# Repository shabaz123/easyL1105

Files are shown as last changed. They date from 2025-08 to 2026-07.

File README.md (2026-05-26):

# easyL1105 - What is it?
This repository contains resources for working with Texas Instruments MSPM0 microcontrollers, and in particular, the MSPM0L1105 microcontroller.
KiCad files, and Gerber files are present for building a simple development board, called easyL1105. 

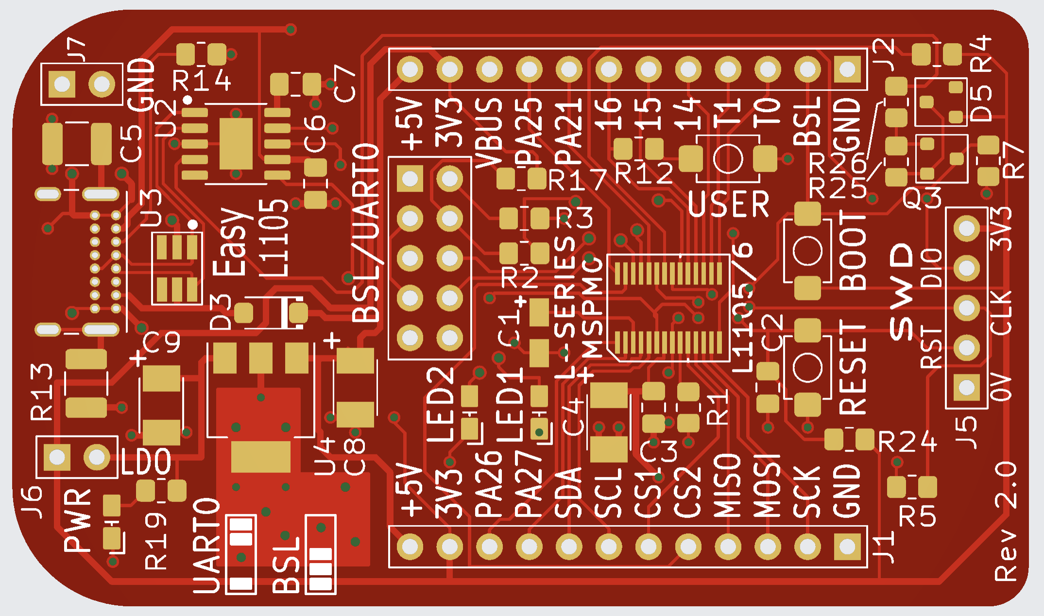
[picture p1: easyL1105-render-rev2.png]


The repository also contains Gerber files for a smaller miniL1105 board:

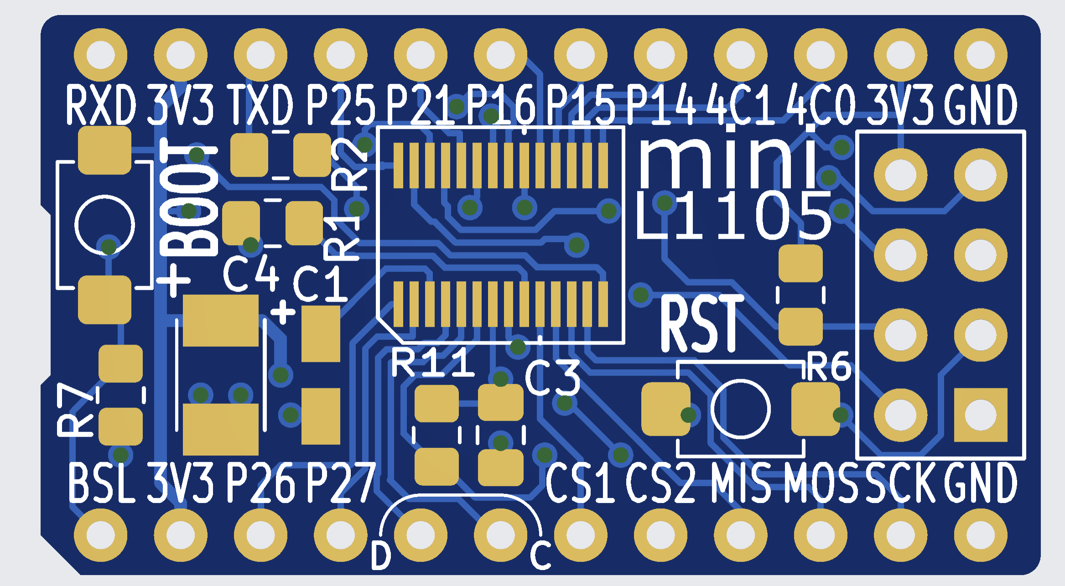
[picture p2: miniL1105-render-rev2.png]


There is also an example starter project, which can be built with Keil or GCC.

# Circuit Diagrams
## easyL1105
<a href="easyL1105_schematic_rev2.pdf">
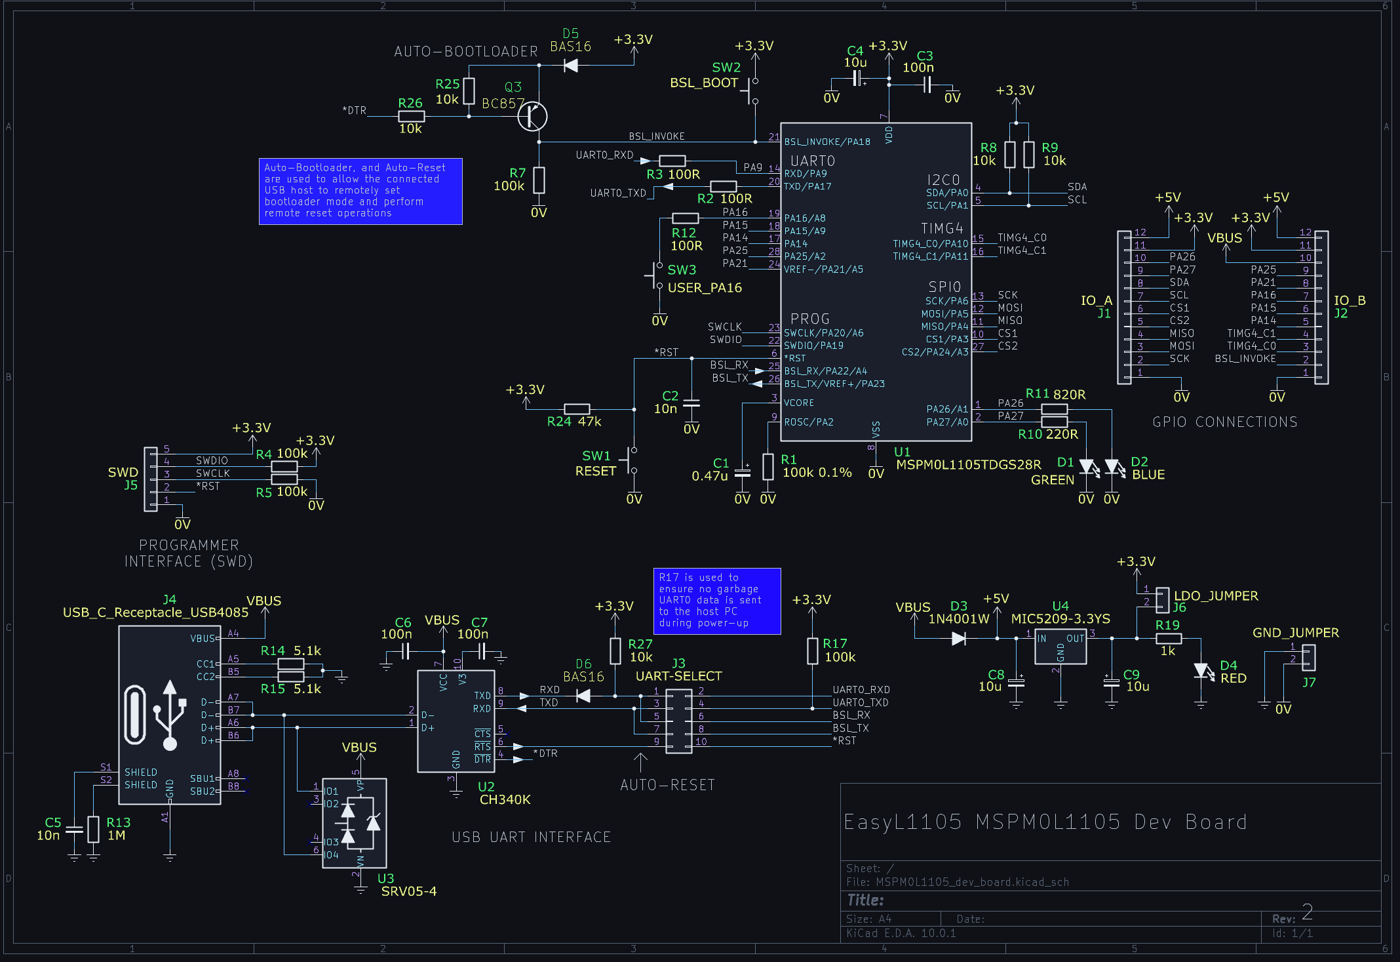
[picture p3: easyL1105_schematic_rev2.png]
  
</a>

## miniL1105
<a href="miniL1105-schematic-rev2.pdf">
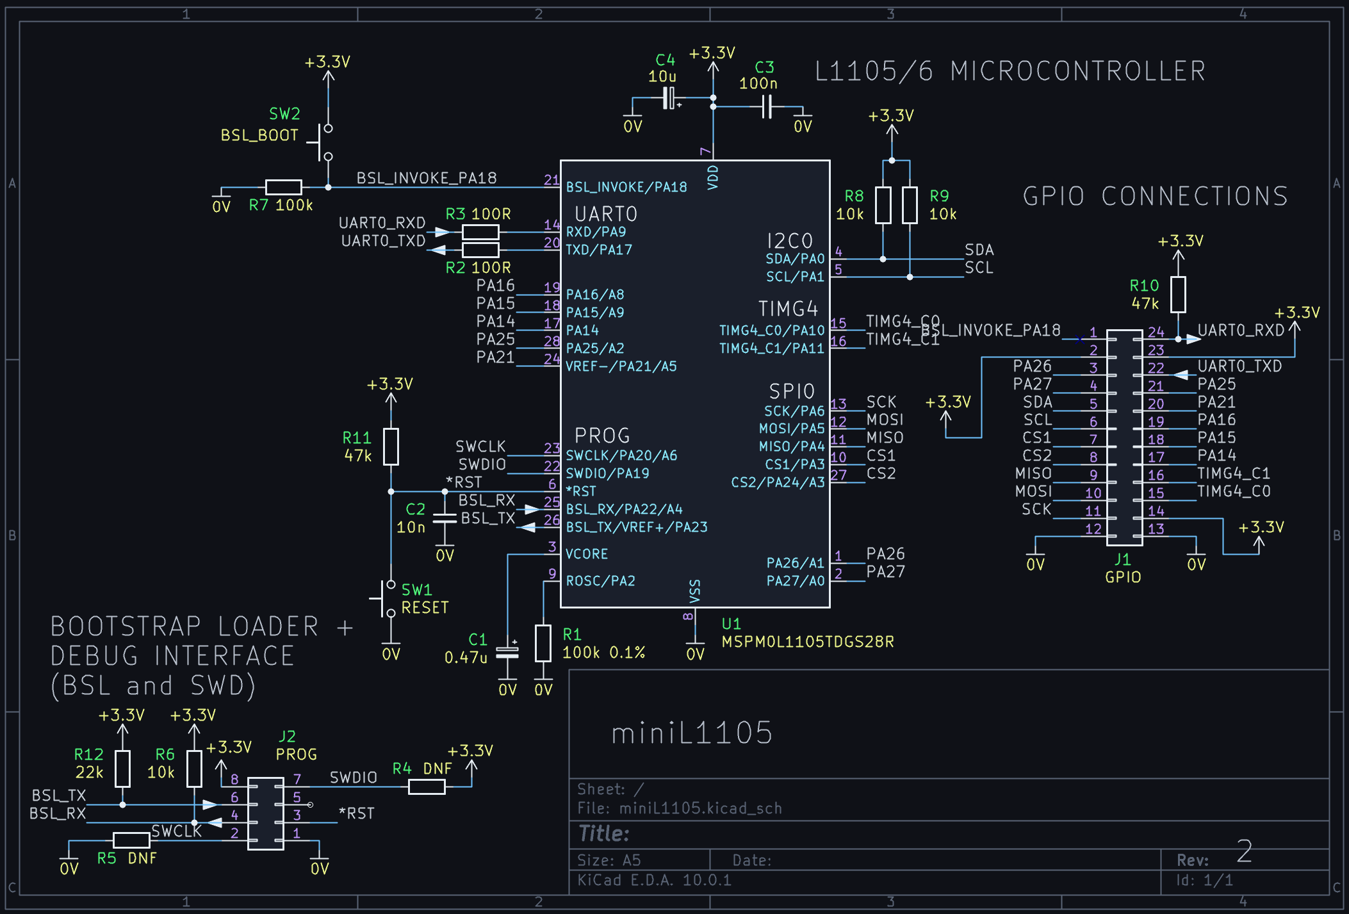
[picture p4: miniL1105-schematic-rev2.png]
  
</a>

## Note for old Rev 1 Boards
The Rev 1 boards had a known bug; they were missing a 47k pull-up resistor from the *RST pin (pin 6 on the microcontroller) to +3.3V. The newer Rev 2 boards do not have this issue.

If you have a Rev 1 board, the fix is easy, it is possible to patch a resistor onto the underside of the PCB, using an 0805 sized resistor and a short length of 30 AWG Kynar wire.

The easyL1105 Rev 1 board allocates pins PA17(TXD) and PA18(RXD) for UART0, but since PA18(RXD) also has a BOOT function for enabling bootloader mode, there is the unfortunate situation that if the "BSL/UART0" board jumpers are configured to direct UART0 to the USB-UART chip, the pin is in BOOT mode during reset. One workaround for now is to not fit the rightmost jumper (rightmost when the "EasyL1105" and "BSL/UART0" text is the correct way up) during board reboot or power-up, and then fit it later. The better fix is in Rev 2, where a different GPIO pin (PA9) is used in place of PA18(RXD), so that it doesn't clash with the BOOT function

# easyL1105 Parts List
NOTE: The parts lists in this repository are for the Rev 1 board. They need to be updated for Rev 2. However, it is easy to read off the schematic what parts are required. 

| REF | QTY | VALUE | DESCRIPTION |
| --- | --- | --- | --- |
| C1 | 1 | 0.47u | Tant Cap Case A example: T491A474M025AT |
| C2, C5 | 2 | 10n | 0805 MLCC Capacitor |
| C3,C6,C7 | 3 | 100n | 0805 MLCC Capacitor |
| C4,C8,C9 | 3 | 10u 16V | Tant Cap Case B example: TAJB106K016RNJ |
| D1 | 1 | GREEN | LED GREEN 0603 |
| D2 | 1 | BLUE | LED BLUE 0603 |
| D3 | 1 | 1N4001W | Diode SOD-123 |
| D4 | 1 | PWR | LED RED 0603 |
| J1, J2, J5, J6, J7 | 1 | Header SIL | Pin Header 2.54mm SIL 40-way (snapped to fit) |
| J3 | 1 | 2x5 DIL | Pin Header 2.54mm DIL 10-way (2x5 way) |
| J4 | 1 | USB4085 | Socket GCT USB4805 / XUNPU USB-B10-BRW |
| R1 | 1 | 100k 0.1% | 0805 Resistor 0.1% |
| R2,R3,R12 | 3 | 100R | 0805 Resistor |
| R4,R5,R7 | 3 | 100k | 0805 Resistor |
| R8,R9,R16 | 3 | 10k | 0805 Resistor |
| R10 | 1 | 220R | 0805 Resistor |
| R11 | 1 | 820R | 0805 Resistor |
| R19 | 1 | 1k | 0805 Resistor |
| R13 | 1 | 1M | 0805 Resistor |
| R14,R15 | 2 | 5.1k | 0805 Resistor |
| SW1, 2, 3 | 3 | Tact Switch | Tact Button 4x3mm GCT SWT0110 |
| U1 | 1 | MSPM0L1105TDGS28R | TI MSPM0 L1105 VSSOP28 DGS |
| U2 | 1 | CH340K | WCH USB UART IC SSOP-10-1EP |
| U3 | 1 | SRV05-4 | ESD Diode Array SOT23-6 |
| U4 | 1 | MIC5209-3.3YS | LDO 3.3V SOT-223 |
| RFIX1 | 1 | 47k | 0805 Resistor, patched between \*RST and 3.3V |
| n/a | 5 | Shorting Jumpers  | Jumpers 2-pin 2.54mm (Red, Black, Green x2, Blue) |

# Example Project
Go into the [**MyStarterProject**](https://github.com/shabaz123/easyL1105/tree/main/MyStarterProject) folder to see an example project called **app_L1105** (and if you plan to use GCC on Linux, then you need the **set_env.sh** file that is also in the MyStarterProject folder; save it to any convenient location). 

Go into the [**app_L1105**](https://github.com/shabaz123/easyL1105/tree/main/MyStarterProject/app_L1105) folder within MyStarterProject, and you'll find README notes explaining how to set up your PC and how to build the code.

If you were creating your own app based on the starter code, then rename the folder MyStarterProject to whatever name you want (for instance, MyLEDProject), and within there, retain the app_L1105 folder name (otherwise, you'd have to modify the contents of IDE files or makefiles). Then, edit the main.c file to do whatever you wish.

# Uploading your Application Firmware to the Microcontroller
Once you have built the example project, you'll want to upload it into the microcontroller. The easyL1105 board has a built-in USB-to-UART adapter. The miniL1105 board will require an external 3.3V logic level USB-UART adapter.

## Set Board Jumpers and Plug into PC
If you're using the easyL1105 board, ensure that two jumpers (green in the photo below) are fitted to direct the USB-UART to **BSL**, and not to UART0. Ensure that the PWR and GND jumpers are fitted (red and black in the photo below).

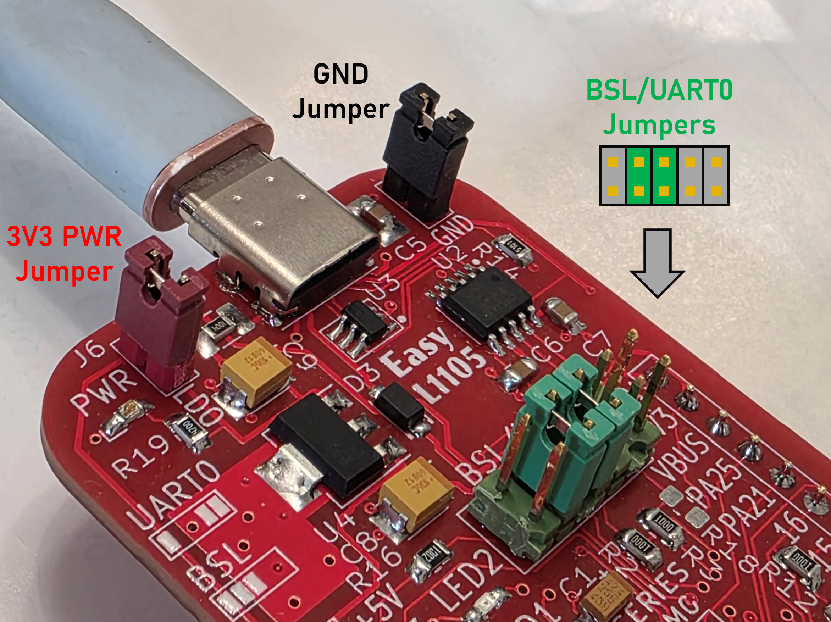
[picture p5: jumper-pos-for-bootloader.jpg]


Attach the board using the USB cable to your PC, and check what port number is associated with it (for example, it may be a number like COM7 if you're using a Windows PC). If you don't see any port, then there may be a fault with the USB-UART circuitry, or an issue with the USB cable perhaps.

## Install and Run UniFlash
Download and install TI UniFlash. Run it, and at the top-right, set **Setting:Manual**. Next, under **Device**, click on **Category:MSP** and then type **MSPM0L110x** and you'll see a selection titled **MSPM0L110X(BOOTLOADER) Serial**. Click to select that.

Next, click on **Start**. 

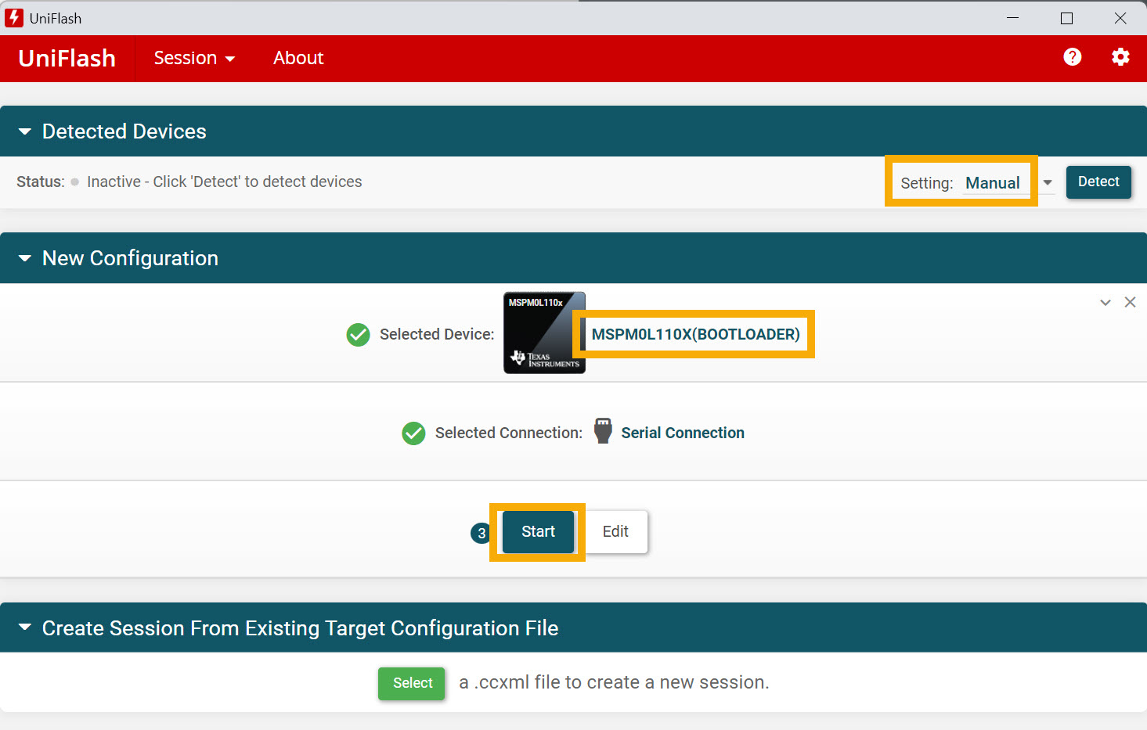
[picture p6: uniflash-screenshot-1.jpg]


You'll see a set of boxes appear. Click the empty text entry box to the right of **Application Image 1** and in the file browser that appears, browse to your built firmware file, which will have a **.hex** suffix, for instance, **app_L1105.hex**.

**Don't** press the Load Image button that appears just yet!

Instead, scroll further down, and you'll see a random COM port selected. In that box, type the correct COM port.

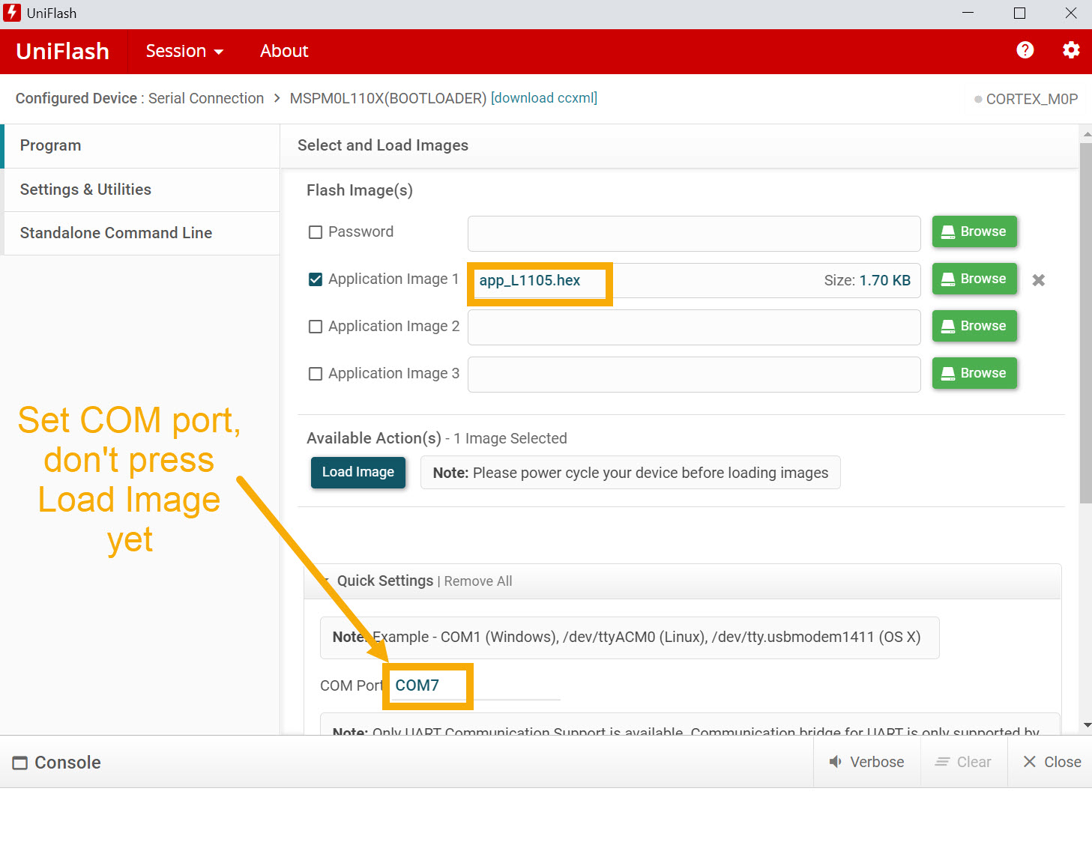
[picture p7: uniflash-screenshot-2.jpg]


## Set Board to Bootloader Mode
Hold down the **BOOT** button on the board, press and release the **RESET** button, then release the **BOOT** button.

## Upload the Firmware
Now you can go back to the **Load Image** button in UniFlash, and press it.

Initially it may take a few seconds (or longer), but eventually you should see output like the following:

```
[21/08/2025, 23:56:17] [INFO] CORTEX_M0P: MSPM0L110x(Bootloader)
[21/08/2025, 23:56:17] [INFO] CORTEX_M0P: Invoking Bootloader....
[21/08/2025, 23:56:18] [ERROR] CORTEX_M0P: Automatic Bootloader invocation failed with response....1
[21/08/2025, 23:56:18] [ERROR] CORTEX_M0P: Try manual Bootloader Invocation...
[21/08/2025, 23:56:19] [INFO] CORTEX_M0P:
[21/08/2025, 23:56:19] [INFO] CORTEX_M0P: BSL Connected
[21/08/2025, 23:56:19] [INFO] CORTEX_M0P: Command Interpreter version: [0x0100] Build ID: [0x0100] Application version: [0x00000000] Active Plugin Interface version: [0x0001] BSL Max buffer size: [0x06C0] BSL Buffer Start address: [0x20000160] BCR Config ID: [0x00000x0001] BSL Config ID [0x00000x0001]
[21/08/2025, 23:56:19] [INFO] CORTEX_M0P: [80] [01] [00] [19] [B2] [B8] [96] [49]
[21/08/2025, 23:56:19] [INFO] CORTEX_M0P: {00}{08} {19} {00} {31} {00} {01} {00} {01} {00} {00} {00} {00} {01} {00} {C0} {06} {60} {01} {00} {20} {01} {00} {00} {00} {01} {00} {00} {00} {49} {61} {57} {8C}
[21/08/2025, 23:56:19] [INFO] CORTEX_M0P: BSL Password is correct!
[21/08/2025, 23:56:19] [INFO] CORTEX_M0P: [80] [21] [00] [21] [FF] [FF] [FF] [FF] [FF] [FF] [FF] [FF] [FF] [FF] [FF] [FF] [FF] [FF] [FF] [FF] [FF] [FF] [FF] [FF] [FF] [FF] [FF] [FF] [FF] [FF] [FF] [FF] [FF] [FF] [FF] [FF] [02] [AA] [F0] [3D]
[21/08/2025, 23:56:19] [INFO] CORTEX_M0P: {00}{08} {02} {00} {3B} {00} {38} {02} {94} {82}
[21/08/2025, 23:56:19] [INFO] CORTEX_M0P: Erasing sectors containing DataBlock starting at 0x0 is successful!
[21/08/2025, 23:56:19] [INFO] CORTEX_M0P: [80] [09] [00] [23] [00] [00] [00] [00] [8F] [02] [00] [00] [34] [27] [34] [14]
[21/08/2025, 23:56:19] [INFO] CORTEX_M0P: {00}{08} {02} {00} {3B} {00} {38} {02} {94} {82}
[21/08/2025, 23:56:19] [INFO] CORTEX_M0P: Erasing memory time elapsed: 0.03107s
[21/08/2025, 23:56:20] [INFO] CORTEX_M0P: [80] [95] [02] [20] [00] [00] [00] [00] [00] [10] [00] [20] [4D] [01] [00] [00] [51] [01] [00] [00] [53] [01] [00] [00] [00] [00] [00] [00] [00] [00] [00] [00] [00] [00] [00] [00] [00] [00] [00] [00] [00] [00] [00] [00] [00] [00] [00] [00] [00] [00] [00] [00] [55] [01] [00] [00] [00] [00] [00] [00] [00] [00] [00] [00] [57] [01] [00] [00] [59] [01] [00] [00] [5B] [01] [00] [00] [5B] [01] [00] [00] [5B] [01] [00] [00] [00] [00] [00] [00] [5B] [01] [00] [00] [00] [00] [00] [00] [00] [00] [00] [00] [00] [00] [00] [00] [00] [00] [00] [00] [5B] [01] [00] [00] [00] [00] [00] [00] [00] [00] [00] [00] [00] [00] [00] [00] [5B] [01] [00] [00] [00] [00] [00] [00] [5B] [01] [00] [00] [5B] [01] [00] [00] [00] [00] [00] [00] [5B] [01] [00] [00] [00] [00] [00] [00] [5B] [01] [00] [00] [00] [00] [00] [00] [00] [00] [00] [00] [00] [00] [00] [00] [5B] [01] [00] [00] [00] [00] [00] [00] [00] [00] [00] [00] [00] [00] [00] [00] [00] [00] [00] [00] [00] [00] [00] [00] [00] [00] [00] [00] [5B] [01] [00] [00] [00] [F0] [02] [F8] [00] [F0] [32] [F8] [0C] [A0] [30] [C8] [08] [38] [24] [18] [2D] [18] [67] [1E] [A2] [46] [AB] [46] [54] [46] [5D] [46] [AC] [42] [01] [D1] [00] [F0] [24] [F8] [7E] [46] [0F] [3E] [B6] [46] [0F] [CC] [01] [26] [33] [42] [00] [D0] [FB] [1A] [33] [43] [A2] [46] [AB] [46] [18] [47] [74] [01] [00] [00] [94] [01] [00] [00] [00] [00] [00] [00] [00] [23] [00] [24] [00] [25] [00] [26] [10] [3A] [01] [D3] [78] [C1] [FB] [D8] [52] [07] [00] [D3] [30] [C1] [00] [D5] [0B] [60] [70] [47] [1F] [B5] [1F] [BD] [10] [B5] [10] [BD] [00] [F0] [27] [F8] [11] [46] [FF] [F7] [F7] [FF] [00] [F0] [59] [F8] [00] [F0] [3F] [F8] [03] [B4] [FF] [F7] [F2] [FF] [03] [BC] [00] [F0] [45] [F8] [00] [00] [06] [48] [00] [47] [FE] [E7] [FE] [E7] [FE] [E7] [FE] [E7] [FE] [E7] [FE] [E7] [03] [48] [04] [49] [02] [4A] [04] [4B] [70] [47] [00] [00] [C1] [00] [00] [00] [60] [00] [00] [20] [00] [10] [00] [20] [00] [0C] [00] [20] [70] [47] [70] [47] [70] [47] [75] [46] [00] [F0] [24] [F8] [AE] [46] [05] [00] [69] [46] [53] [46] [C0] [08] [C0] [00] [85] [46] [18] [B0] [20] [B5] [FF] [F7] [E1] [FF] [60] [BC] [B6] [46] [00] [26] [00] [27] [C0] [C5] [C0] [C5] [C0] [C5] [C0] [C5] [C0] [C5] [C0] [C5] [C0] [C5] [C0] [C5] [40] [3D] [49] [08] [49] [00] [8D] [46] [70] [47] [10] [B5] [04] [46] [C0] [46] [C0] [46] [20] [46] [FF] [F7] [BA] [FF] [10] [BD] [00] [48] [70] [47] [00] [00] [00] [20] [01] [49] [18] [20] [AB] [BE] [FE] [E7] [26] [00] [02] [00] [70] [47] [81] [1E] [09] [1F] [00] [BF] [FC] [D2] [70] [47] [82] [B0] [1A] [48] [1A] [49] [41] [60] [1A] [49] [01] [60] [10] [20] [FF] [F7] [F2] [FF] [19] [48] [81] [21] [01] [60] [01] [20] [80] [06] [17] [49] [08] [60] [08] [63] [7D] [22] [92] [01] [0B] [46] [20] [3B] [18] [60] [00] [23] [1C] [46] [02] [E0] [64] [1C] [64] [2C] [08] [D0] [00] [93] [00] [9D] [95] [42] [F8] [D2] [00] [BF] [00] [9D] [6D] [1C] [00] [95] [F7] [E7] [08] [60] [00] [23] [1C] [46] [02] [E0] [64] [1C] [64] [2C] [E6] [D0] [01] [93] [01] [9D] [95] [42] [F8] [D2] [00] [BF] [01] [9D] [6D] [1C] [01] [95] [F7] [E7] [C0] [46] [00] [08] [0A] [40] [03] [00] [00] [B1] [01] [00] [00] [26] [6C] [80] [42] [40] [A0] [12] [0A] [40] [00] [00] [00] [00] [90] [02] [00] [00] [00] [00] [00] [20] [60] [00] [00] [00] [08] [01] [00] [00] [90] [02] [00] [00] [00] [0C] [00] [20] [00] [04] [00] [00] [08] [01] [00] [00] [5D] [8C] [43] [C0]
[21/08/2025, 23:56:20] [INFO] CORTEX_M0P: {00}{08} {02} {00} {3B} {00} {38} {02} {94} {82}
[21/08/2025, 23:56:20] [INFO] CORTEX_M0P: Programming memory time elapsed: 0.7061s
[21/08/2025, 23:56:20] [INFO] CORTEX_M0P: Number of bytes programmed: 656 bytes
[21/08/2025, 23:56:20] [INFO] CORTEX_M0P: Programming speed: 0.9073kByte/s
[21/08/2025, 23:56:20] [ERROR] CORTEX_M0P: Data Block Size less than 1KB!!! Verification Failed for Datablock at0x0
[21/08/2025, 23:56:20] [INFO] CORTEX_M0P: Verifying memory time elapsed: 0s
[21/08/2025, 23:56:20] [INFO] CORTEX_M0P: System Reset Issued!!!
[21/08/2025, 23:56:20] [INFO] CORTEX_M0P: System reset is executed!
[21/08/2025, 23:56:20] [INFO] CORTEX_M0P: [80] [01] [00] [40] [E2] [51] [21] [5B]
```

UniFlash may also report an error but still work (some versions of it are buggy like that) and if it went well, your board should immediately begin execution of the firmware, and flash LEDs if you're using the MyStarterProject app_L1105 on the easyL1105 board.

If UniFlash output doesn't look similar to that shown above, repeat the steps starting from the **Set Board to Bootloader Mode** section, in case it's a UniFlash issue.

# Non-UniFlash Option: Python Programmer
If you wish to use Python to program the chip rather than UniFlash, then see [the MSPM0 Programmer Python](https://github.com/shabaz123/easyL1105/tree/main/mspm0_programmer/python) folder.

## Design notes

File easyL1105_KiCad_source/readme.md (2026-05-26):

KiCad project files for the easyL1105 Rev 2 board

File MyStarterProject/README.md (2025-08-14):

# MyStarterProject
This folder contains app_L1105, which is the source code for a simple MSPM0L1105 microcontroller project.

To use, create a folder with your desired project name (i.e. instead of **MyStarterProject**, call it (say) **MotorController** or **LEDController** etc).

Inside that folder, place the app_L1105 folder.

If you're using Linux or Max, you'll also need the set_env.sh file, place it anywhere convenient.

Next, go inside the app_L1105 folder and follow the README.md file there, which explains how to set up your PC for building the MSPM0L1105 project.

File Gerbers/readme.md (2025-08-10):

Gerber files zipped up, ready for sending to any PCB manufacturer

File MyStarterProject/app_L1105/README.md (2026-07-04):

## Introduction

This guide explains how to set up your PC (Windows/Mac/Linux) in order to build a simple MSPM0L1105 starter project.

For ease of coding, this project uses [DriverLib](https://software-dl.ti.com/msp430/esd/MSPM0-SDK/latest/docs/english/driverlib/mspm0l11xx_l13xx_api_guide/html/modules.html) which is a simple low-level API for accessing microcontroller integrated peripherals.

Note: The starter project is called **app_L1105**. If (say) your project is about motor control, you could create a **motor_control** folder, and then drop the app_L1105 folder within it, and simply accept that the app_L1105 name will remain. If you don't want that, you'll have to rename the **app_L1105/keil/app_L1105.uvprojx** file, and also edit the contents of that file, and/or modify the **app_L1105/gcc/makefile** file, depending on if you're building with Keil, GCC, or both. I recommend you keep the app_L1105 name, and simply change the top-level folder name as mentioned.

### Low-Power Recommendations
TI recommends to terminate unused pins by setting the corresponding functions to
GPIO and configure the pins to output low or input with internal
pullup/pulldown resistor.

## Note
The steps here were tested with these combinations:

* Windows with Keil
* Windows with GCC
* Linux with GCC

Other combinations should work, but were untested.

## Setting up your Windows PC
If you're using Windows, download and install the [TI MSPM0 SDK](https://www.ti.com/tool/MSPM0-SDK) in folder **C:\ti** (if you use a different folder, then you'll need to edit some files later, such as app_L1105.uvprojx if you're using Keil, and environment variables if you're using GCC, so it's recommended to initially just use the C:\ti folder if you can). It will install itself into a sub-folder, called something like mspm0_sdk_2_05_01_00. 

If you're using Linux or Mac, the SDK is obtained using a git clone command discussed later.

Next, follow the setting-up steps below depending on whether you're using Keil uVision or ARM GCC.

### Setting up to use Keil
**NOTE:** If the TI MSPM0 SDK folder is *not* precisely called **mspm0_sdk_2_05_01_00** then you'll need to edit the **app_L1105.uvprojx** file (search-and-replace all instances of mspm0_sdk_2_05_01_00 and replace with what you've got).

Download and install and activate [Keil uVision](https://www.keil.arm.com/mdk-community/) (community edition). 

Next, launch uVision and go to **Project->Manage->PackInstaller**, wait for it to refresh over the Internet, and then in the left pane, navigate to **TexasInstruments->MSPM0Series->MSPM0L110X->MSPM0L1105** and click on the name, and then notice that in the right pane, at the top, in the **Pack** column, in the **Device Specific** section, the first entry will be **TexasInstruments:MSPM0L11XX_L13XX_DFP**. In the **Action** column, click on **Install**.

Now you can move on to the **Building with Keil uVision** section.

### Setting up to use ARM GCC on Windows
Download and install the [ARM GNU Toolchain](https://developer.arm.com/downloads/-/arm-gnu-toolchain-downloads). If you're using Windows, then file you need is called something like **arm-gnu-toolchain-13.3.rel1-mingw-w64-i686-arm-none-eabi.zip** but use the latest. You may already have it installed on your PC if you've worked with other microcontrollers (such as Pi Pico RP2040). It will have installed into a folder, such as **C:\Program Files (x86)\Arm GNU Toolchain arm-none-eabi\13.3 rel1**

Open up your Windows Environment Variables, and create two user variables as follows:

```GCC_ARMCOMPILER_MSP   C:\Program Files (x86)\Arm GNU Toolchain arm-none-eabi\13.3 rel1```

```MSPM0_SDK_INSTALL_DIR     C:\ti\mspm0_sdk_2_05_01_00```

You will need to set those variables with your actual paths.

Next, examine your PATH user variable, and see if there's any location suitable for placing a utility application. In my case, I had a folder called c:\users\myusername\.local\bin but if you cannot find anything suitable, then create a path called (say) c:\tools\bin

Go to [EZWinPorts](https://sourceforge.net/projects/ezwinports/files/) and download the file called **make-4.4.1-without-guile-w32-bin.zip** (the number 4.4.1 may be different, that's OK). Open the zip file, and locate **make.exe** (it will be in the **bin** subfolder in the zip file) and place it in your tools folder (**c:\tools\bin** or anywhere else provided it is a folder in your PATH variable).

Now you can move on to the **Building with ARM GCC** section.

### Setting up to use ARM GCC on Ubuntu Linux
Download and install the [ARM GNU Toolchain](https://developer.arm.com/downloads/-/arm-gnu-toolchain-downloads). To do that, you'll need to have downloaded a file with a name like **gcc-arm-none-eabi-10.3-2021.10-x86_64-linux.tar.bz2** (but download the latest) from the ARM website and type the following to install it; there is probably a better way, but this works for now (you'll need to use **su**, or you can prefix each command with **sudo**):

```
su
tar xjf gcc-arm-none-eabi-10.3-2021.10-x86_64-linux.tar.bz2 -C /usr/share
cd /usr/share/gcc-arm-none-eabi-10.3-2021.10
ln -s /usr/share/gcc-arm-none-eabi-10.3-2021.10/bin/arm-none-eabi-gcc /usr/bin/arm-none-eabi-gcc
ln -s /usr/share/gcc-arm-none-eabi-10.3-2021.10/bin/arm-none-eabi-g++ /usr/bin/arm-none-eabi-g++
ln -s /usr/share/gcc-arm-none-eabi-10.3-2021.10/bin/arm-none-eabi-gdb /usr/bin/arm-none-eabi-gdb
ln -s /usr/share/gcc-arm-none-eabi-10.3-2021.10/bin/arm-none-eabi-size /usr/bin/arm-none-eabi-size
ln -s /usr/share/gcc-arm-none-eabi-10.3-2021.10/bin/arm-none-eabi-objcopy /usr/bin/arm-none-eabi-objcopy
apt install libncurses-dev
ln -s /usr/lib/x86_64-linux-gnu/libncurses.so.6 /usr/lib/x86_64-linux-gnu/libncurses.so.5
ln -s /usr/lib/x86_64-linux-gnu/libtinfo.so.6 /usr/lib/x86_64-linux-gnu/libtinfo.so.5
```

Create a development folder. I use a folder /home/MY_USER_NAME/development. Go to that folder, and then type the following to obtain the MSPM0 SDK:
```
git clone https://github.com/TexasInstruments/mspm0-sdk.git
```

Next, edit the [MyStarterProject/set_env.sh](https://github.com/shabaz123/easyL1105/blob/main/MyStarterProject/set_env.sh) file (you don't need to keep it at that folder, you can move that file to anywhere convenient) and ensure the paths in there are correct. There are two paths there, one for the ARM GNU Toolchain, and one for the MSPM0 SDK.

Now, whenever you wish to work with the your projects, just remember to go to the folder containing set_env.sh, and type:

```
source ./set_env.sh
```

Now you can move on to the **Building with ARM GCC** section.

## Building with Keil uVision
Launch uVision, and then go to **Project->OpenProject** and then navigate to the **app_L1105** folder, and within that, open the **Keil** folder, and select **app_L1105.uvprojx** in that folder.

The project will open, and you'll see the source code files in the left side Project pane. For instance, the **main.c** file can be accessed by expanding **app_L1105->Source** in that project files tree.

To build the code, click on **Project->BuildTarget**.

## Building with ARM GCC (Windows or Linux or Mac)
If you're using Windows, then launch **PowerShell**, otherwise if you're using Linux or Mac, you'll be using a shell (terminal).

(If you're using Linux or Mac, remember to source your set_env.sh file (by typing **source ./set_env.sh"**) from wherever you saved that file).

Navigate to the **app_L1105** folder, and within that, go to the **GCC** folder. 

You'll see a **makefile** in there. Simply type: **make** and the code should build. To remove the outputs, type: **make clean**

If you wish to build a Release version, type **make DEBUG=0** (you may need to type **make clean** first).

## Making use of Integrated Peripherals using TI SysConfig
Although there is [DriverLib documentation](https://software-dl.ti.com/msp430/esd/MSPM0-SDK/latest/docs/english/driverlib/mspm0l11xx_l13xx_api_guide/html/modules.html) it's useful to auto-generate code, either to directly use, or to inspect and reuse as required, using a tool called [SysConfig](https://www.ti.com/tool/SYSCONFIG).

Once you have installed SysConfig, start it up from the command line (for instance, using Windows Powershell), using the following syntax:

```
C:\ti\sysconfig_1.27.1\sysconfig_gui.bat --product "C:/ti/mspm0_sdk_2_10_00_04/.metadata/product.json"  --device "MSPM0L1105" --package "VSSOP-28(DGS28)" --compiler gcc
```

When it starts up, you have to, very importantly, click on Board, so that a green check-mark appears against it. 

<img width="100%" align="left" src="../../sysconfig-board.jpg">

Then, you can click on any integrated peripheral further below it, for instance GPIO as shown in the screenshot below, and configure as follows if you want an output pin. Notice on the right side, there are two files listed called ti_msp_dl_config.c and ti_msp_dl_config.h and those will contain the code you need. Click on the all files icon and save all to any folder, then you can explore those two files.

<img width="100%" align="left" src="../../sysconfig-gpio.jpg">

From the .c and .h files, it is possible to figure out what to put in the main code. Note that this isn't the way you're supposed to use those files, but for the purposes of this quick example, it will do for now.

## Modifying Stack Allocations
If you're using Keil, open the startup_mspm0l110x_uvision.s file, and there will be an entry there similar to:

Stack_Size      EQU     0x00000400

0x400 (hex) is 1024 bytes in decimal. Change the 0x00000400 size as desired, but you'll also need to change instances of 0x00000400 in mspm0l1105.sct too. The stack is configured in mspm0l1105.sct to start at 0x20001000 (top of 4kBytes of RAM) and grow down to 0x20000c00 (i.e. 1024 bytes size).

Note that statically allocated variables start at the bottom of the RAM, followed by Heap (used for malloc'd space) and this grows up, and it could possibly hit the stack.

If you're using GCC, the current linker file (C:\ti\mspm0_sdk_2_05_01_00\source\ti\devices\msp\m0p\linker_files\gcc\mspm0l1105.lds) doesn't specify a limit to the stack size; it merely starts at 0x20001000 (top of 4kBytes of RAM) and grows down as much as required.

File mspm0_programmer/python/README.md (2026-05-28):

# MSPM0 BSL Programmer
This program can be used to program MSPM0L110x devices via USB Serial Bootloader (BSL). It has some advantages over TI UniFlash, specifically it's quicker, less bloated, and (if you're using an EasyL1105 board) supports the ability to automatically boot/reset the target.

# Requirements:
Python

pySerial:  pip install pyserial

# How Does it Work?
Compile/build your MSPM0 application as usual, until you have a .hex (Intel Hex format) file generated.

Next, connect the MSPM0 board to the PC using a USB-UART adapter.

Run the Python program using a command such as:
```
python ./mspm0_prog.py --port COM15 myapp.hex
```

It will prompt you to hold down the BOOT button, press and release RESET, and then release the BOOT button. After that, follow the prompt and the new firmware should be programmed in seconds.

When the Python code is run, in the background it is first internally converting the .hex file into an 'interim' format which I've called a .flash format, and then the Python code converts the .flash format into serial commands that the MSPM0 bootloader understands, sent over a USB UART adapter.

The reason for the interim format is that it is closer to what the MSPM0 requires, plus, it will be useful in future for using with other programmer software.

# Usage
## Program a MSPM0 chip using the .hex file
```
python ./mspm0_prog.py [--port COMx] [--auto] firmware.hex
```
Example:

python ./mspm0_prog.py --port COM15 myapp.hex

## Just generate a .flash file

```
python ./mspm0_prog.py --port none --saveflashfile firmware.hex
```
The above command won't program the MSPM0 chip (since ***port none*** is specified), but will just generate a .flash file with the same name as the source .hex file.

Example:

python ./mspm0_prog.py --port none --saveflashfile myapp.hex

The above will generate a myapp.flash file

## Program a MSPM0 chip from a .flash "interim" file
NOTE: This is todo, it is not currently implemented!

```
python ./mspm0_prog.py [--port COMx] [--auto] firmware.flash
```

By specifying a filename with .flash, the code will program the MSPM0 from the flash file, rather than from the .hex file. Not currently implemented!

## Simulating an MSPM0
NOTE: This is not normally something you'd want to do, but might be helpful for testing programmer software, if a real MSPM0 is not at hand.

```
python ./mspm0_prog.py [--port COMx] sim
```

By specifying ***sim***, the code will simulate the MSPM0 BSL and respond to commands

## Additional flags

The ***--auto*** option is used if you have an MSPM0 device with special connections from the UART chip to the RESET and BOOT connections. If so, the Python code will not prompt the user to perform the BOOT/RESET button sequence, and will instead automatically try to boot/reset the device

Example:

```
python ./mspm0_prog.py --port COM5 --auto myprog.hex
```

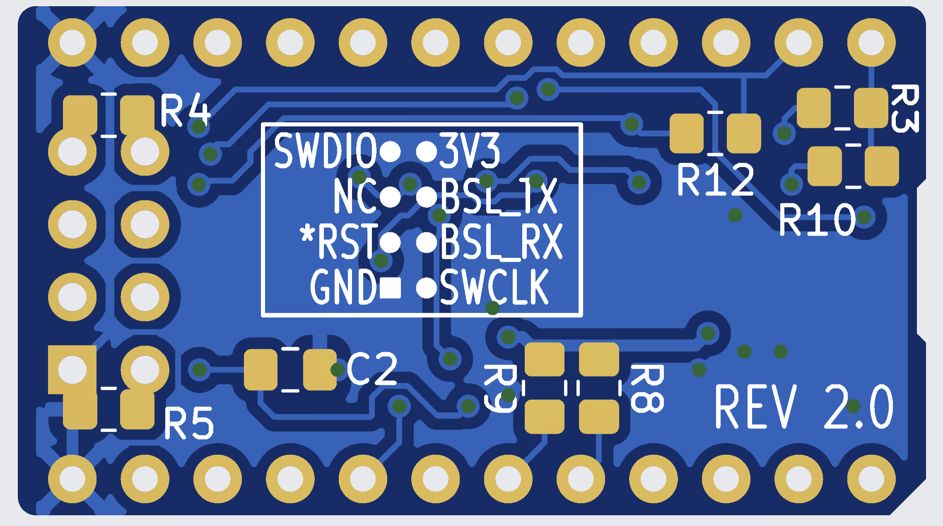
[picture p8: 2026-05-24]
miniL1105-render-rev2-underside.png

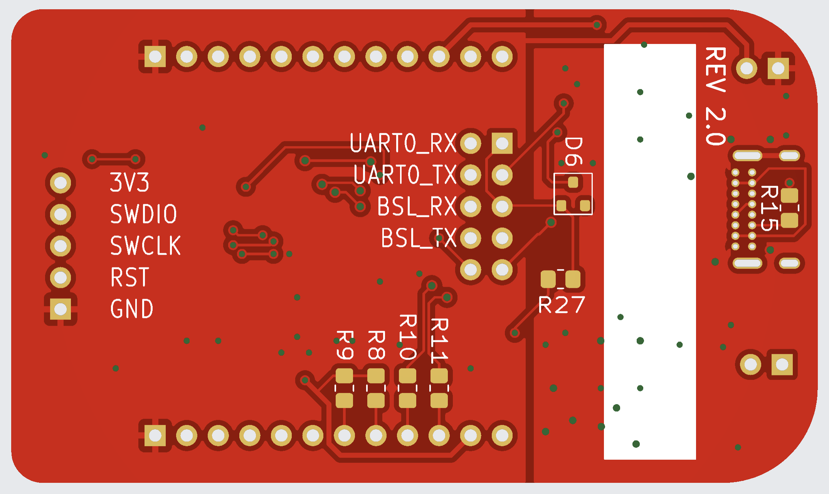
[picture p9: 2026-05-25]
easyL1105-render-underside-rev2.png

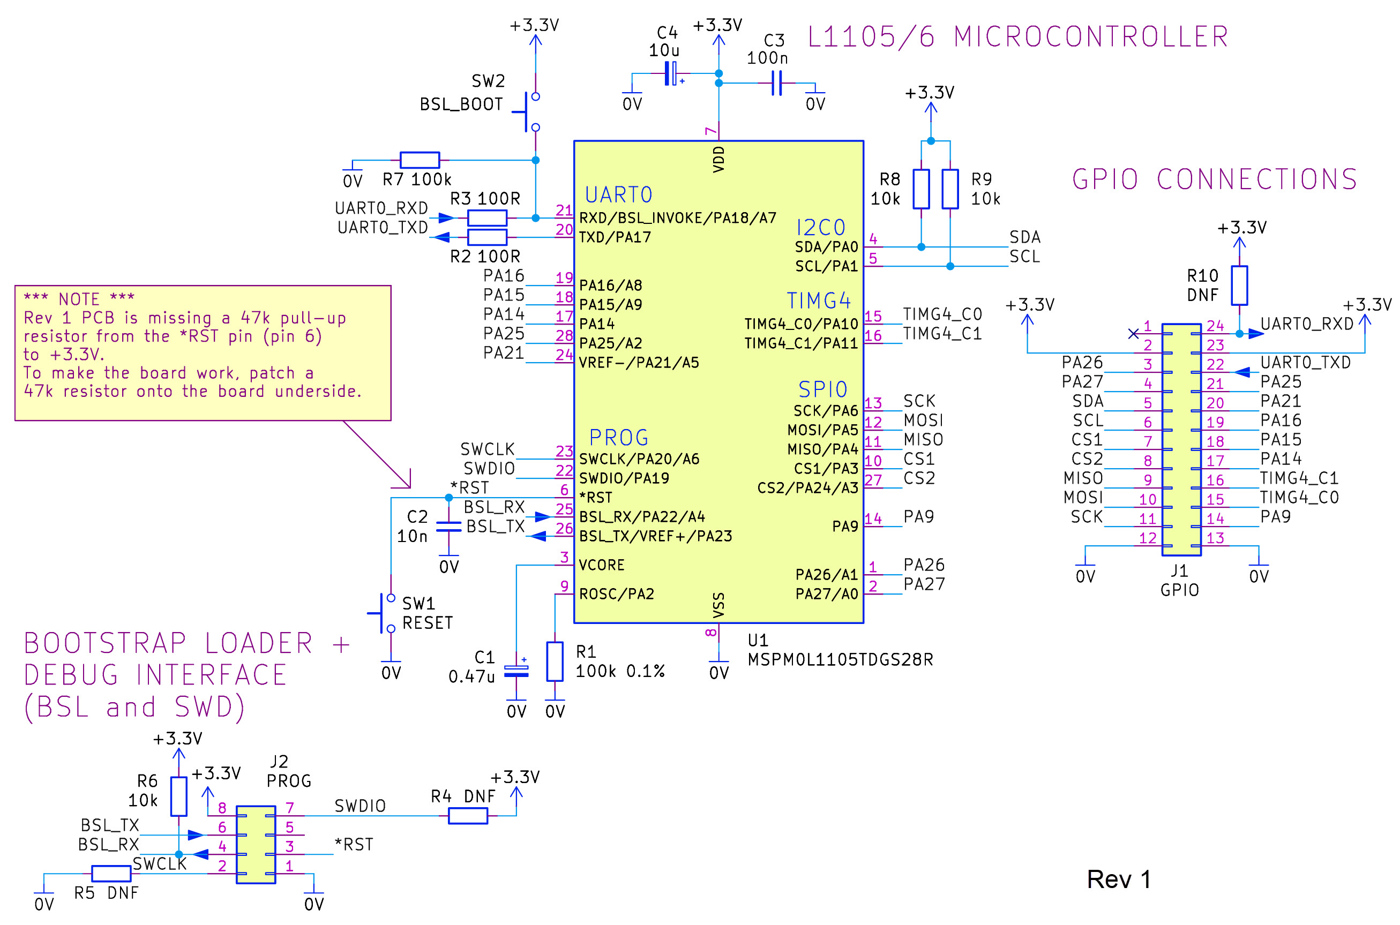
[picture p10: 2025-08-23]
minil1105-sch-jpeg-rev1.jpg

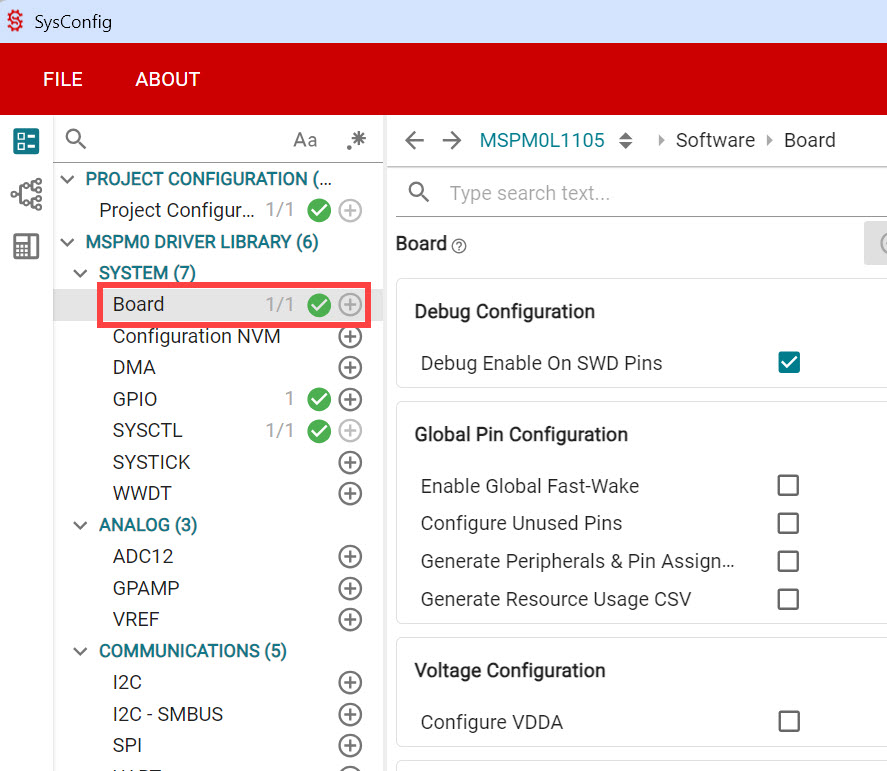
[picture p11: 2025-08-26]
sysconfig-board.jpg

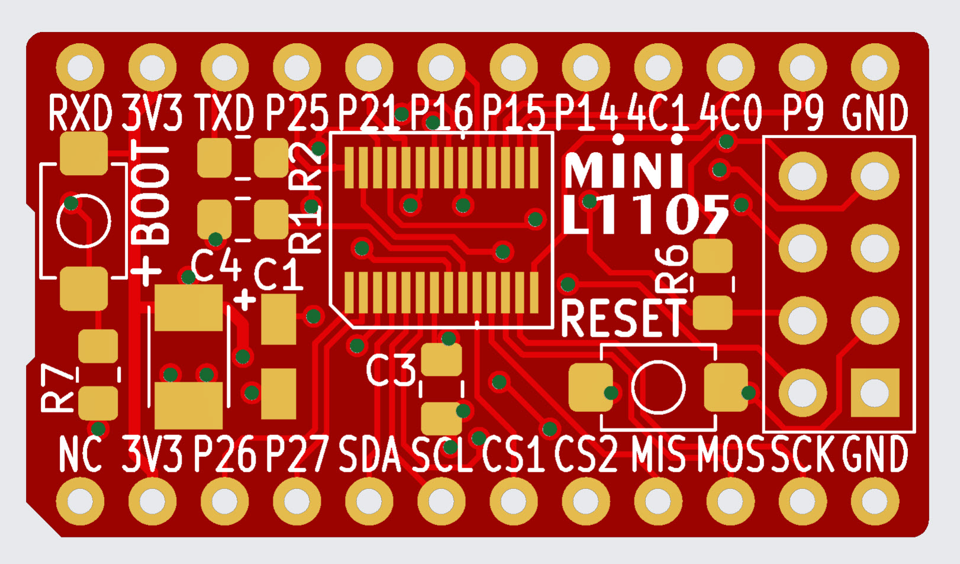
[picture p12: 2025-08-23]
miniL1105-render.jpg

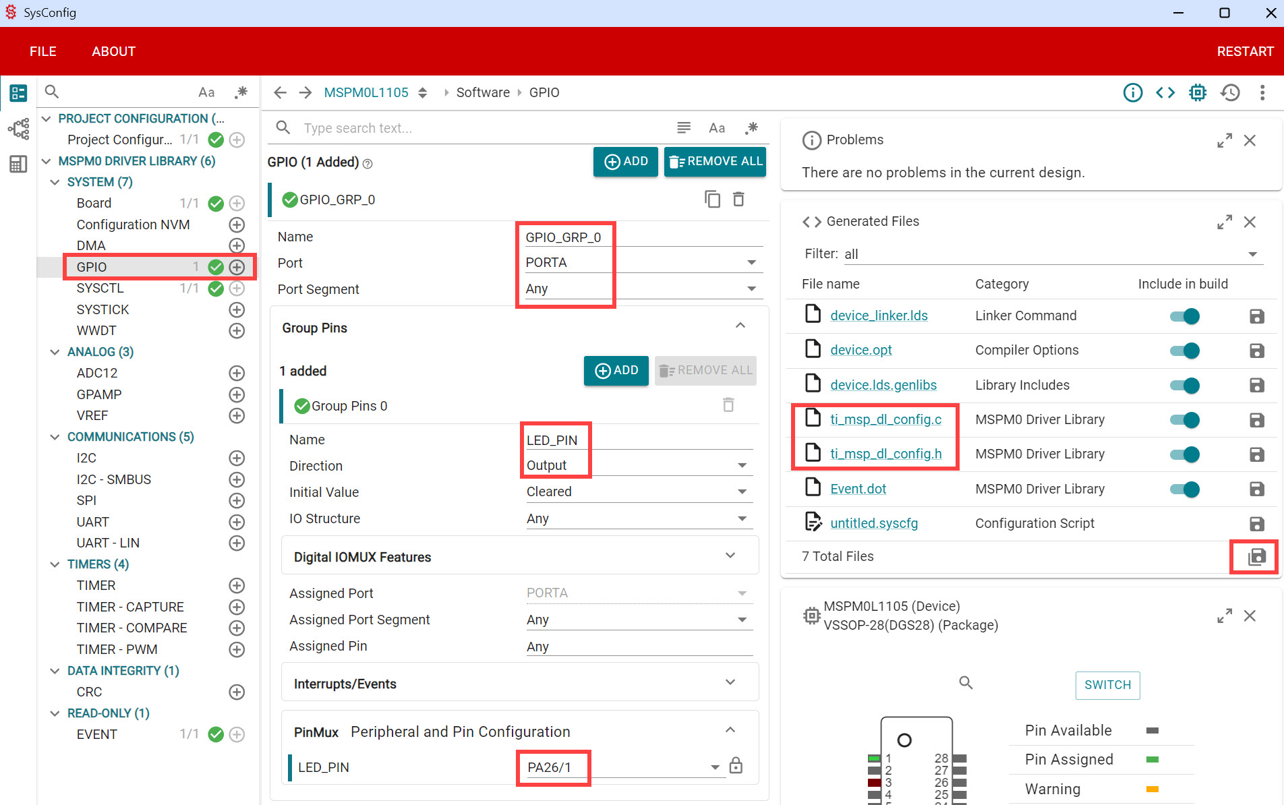
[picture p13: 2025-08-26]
sysconfig-gpio.jpg

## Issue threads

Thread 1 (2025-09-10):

example doesn't run when UART jumpers mounted

jancumps, 2025-09-10:
I noticed that example and other firmware doesn't start when 2 UART jumpers are mounted
(same for other firmware, with or without UART use)

replicate:

- verify that code works without UART jumpers:
- load example (tested with python bootloader and XDS110 debugger)
- don't mount UART jumpers
- plug USB in PC: 2 LEDs blink. Test passes

- effect with UART jumpers:
- mount power jumpers
- mount 2 UART jumpers
- no BLS jumpers
- tried with and without reset jumper
- plug USB in PC. **_LEDs don't blink_**
- unplug, remove UART jumpers
- plug USB in PC: 2 LEDs blink. Test passes again

shabaz123, 2025-09-27:
Sorry, just seeing this now. You're right, it's an annoying issue, caused by the UART line being pulled up during reset when the UART is wired up. Will be resolved in rev 2 as discussed at that comment, meanwhile the only workarounds are to either use a different pin rather than PA18 for RXD, or only fit the jumper after the board has booted up.

Closed 2025-09-27.

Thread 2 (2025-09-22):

Python bootloader error Invalid Memory Range

jancumps, 2025-09-22:
I'm trying to bootload an ihex file to EasyL1105.
The bootloader unclocks successfully. but fails with 2 errors:

first when creating the intermediate file:
```
End of file record (0x01) on line 130, finished reading .hex file
Sanity checking the .hex content...
**** ERROR: Length of addr_len_list (3) does not match length of data_list (2), aborting! ****

```

It doesn't abort. It creates the intermediate file, asks for button pushes and tries to load. Note that the Address 2 length = 0 bytes.

```
Bootloader unlocked successfully
Performing Flash Range Erase (0x23) operation(s)
Entry 0: Address: 0x00000000, Length: 1024 bytes, Erase Start Block: 0x00000000, Erase End Block: 0x00000000
Entry 1: Address: 0x00000400, Length: 1024 bytes, Erase Start Block: 0x00000400, Erase End Block: 0x00000400
Entry 2: Address: 0x00000800, Length: 0 bytes, Erase Start Block: 0x00000800, Erase End Block: 0x00000400
```

Then it successfully programs Entry 0 and 1. It fails at Entry 2, where it tries to write 1024 bytes

```
Erasing Flash block: Address 0x00000800, length 1024 bytes
Sending Flash Range Erase command: 8009002300080000000400008cb36c96
Waiting for response from MSPM0 chip

***** ERROR: Failed to erase flash range at address 0x00000800, exiting. ******
Invalid Memory Range

```

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

I will attach a zip that includes the hex, map, etc...
**warning: it's a low power design. Don't actually load it**

shabaz123, 2025-09-27:
Sorry for not seeing this earlier. It was caused by my misunderstanding the meaning of some bytes in the flash erase command. I thought the bytes were to represent the length of erase required, but actually they should have indicated the last address of the bytes to be erased. It is resolved now in the code.

Closed 2025-09-27.

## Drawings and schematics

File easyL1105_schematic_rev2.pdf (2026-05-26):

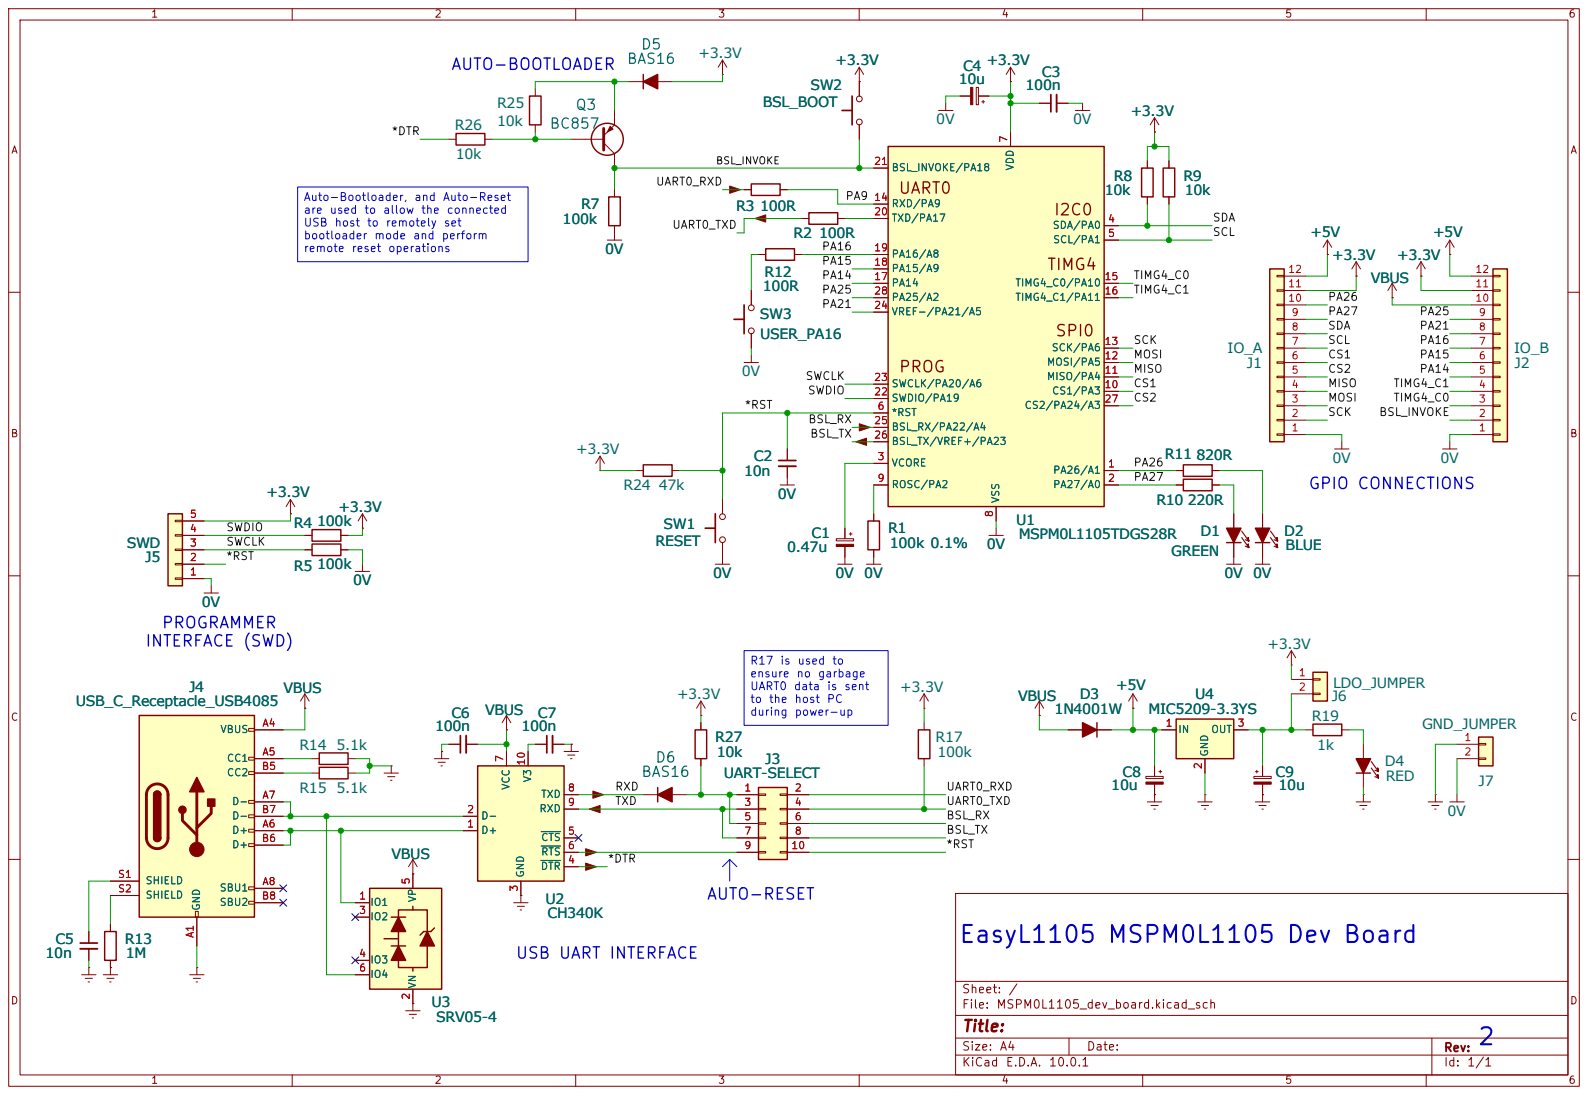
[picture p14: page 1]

Auto-Bootloader, and Auto-Reset are used to allow the connected USB host to remotely set bootloader mode and perform

ensure no garbage UART0 data is sent

to the host PC

3 DTR 4 CTS 5 RTS 6 VCC

Size: A4 | Rev:
KiCad E.D.A. 10.0.1 | Id: 1/1

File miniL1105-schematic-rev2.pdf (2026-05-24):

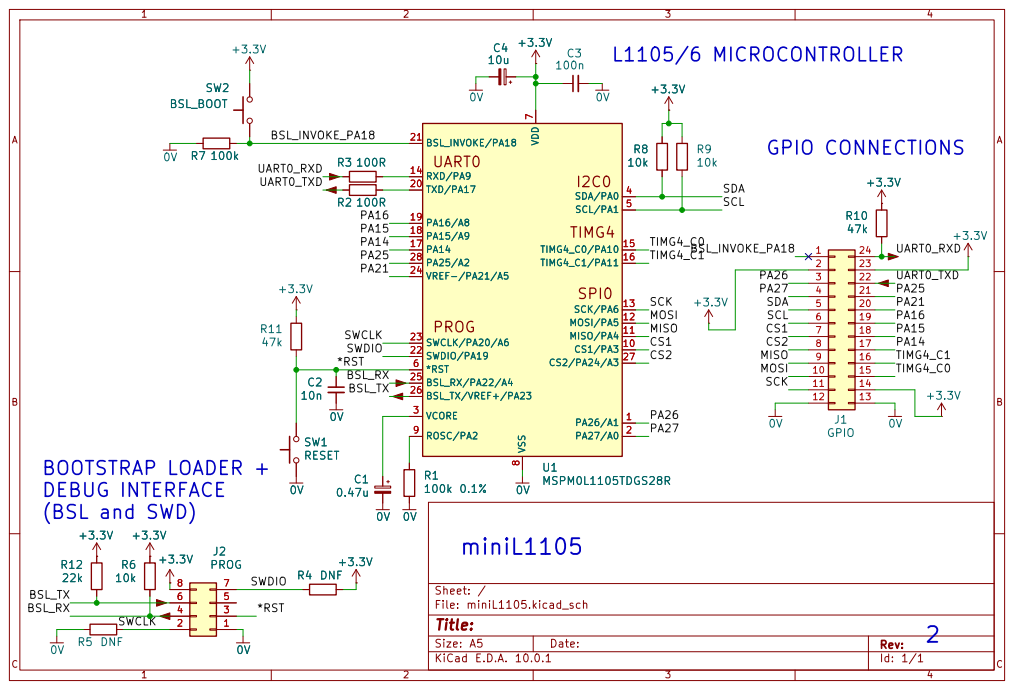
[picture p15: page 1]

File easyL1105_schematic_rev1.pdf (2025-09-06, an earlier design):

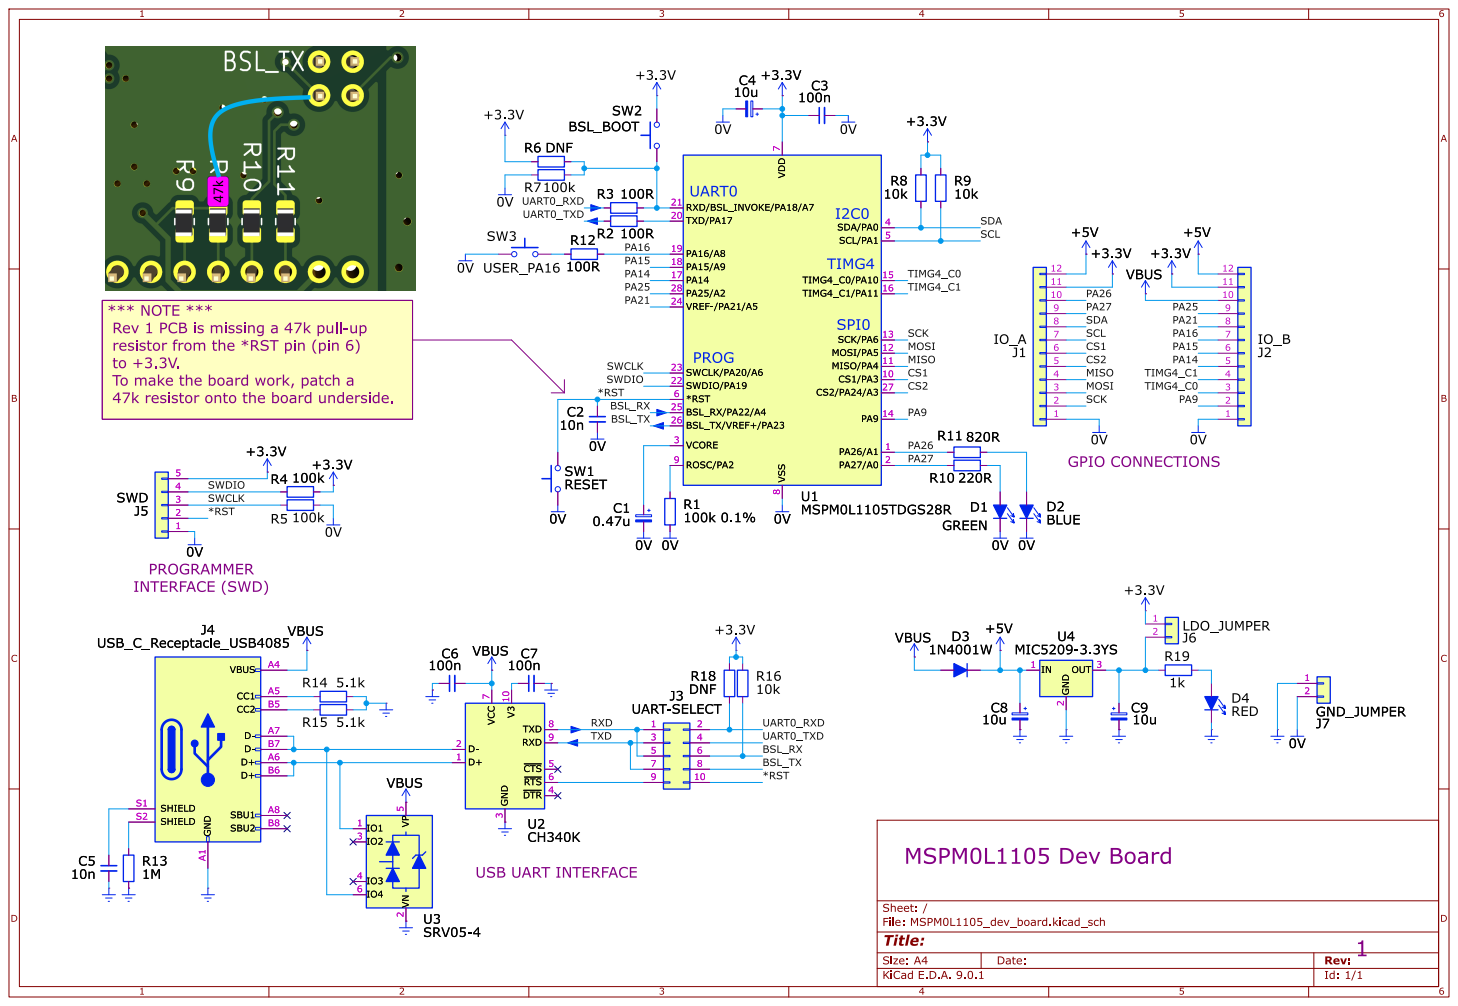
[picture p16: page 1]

*** NOTE *** Rev 1 PCB is missing a 47k pull-up

resistor from the *RST pin (pin 6)
To make the board work, patch a
47k resistor onto the board underside.

8 RXD 8 RXD TXD | 3 3
9 ~{CTS}5 ~{RTS}6 ~{DTR}4 U2 | 5 5

MSPM0L1105 Dev Board

Id: 1/1 Title: File: MSPM0L1105_dev_board.kicad_sch Sheet: /

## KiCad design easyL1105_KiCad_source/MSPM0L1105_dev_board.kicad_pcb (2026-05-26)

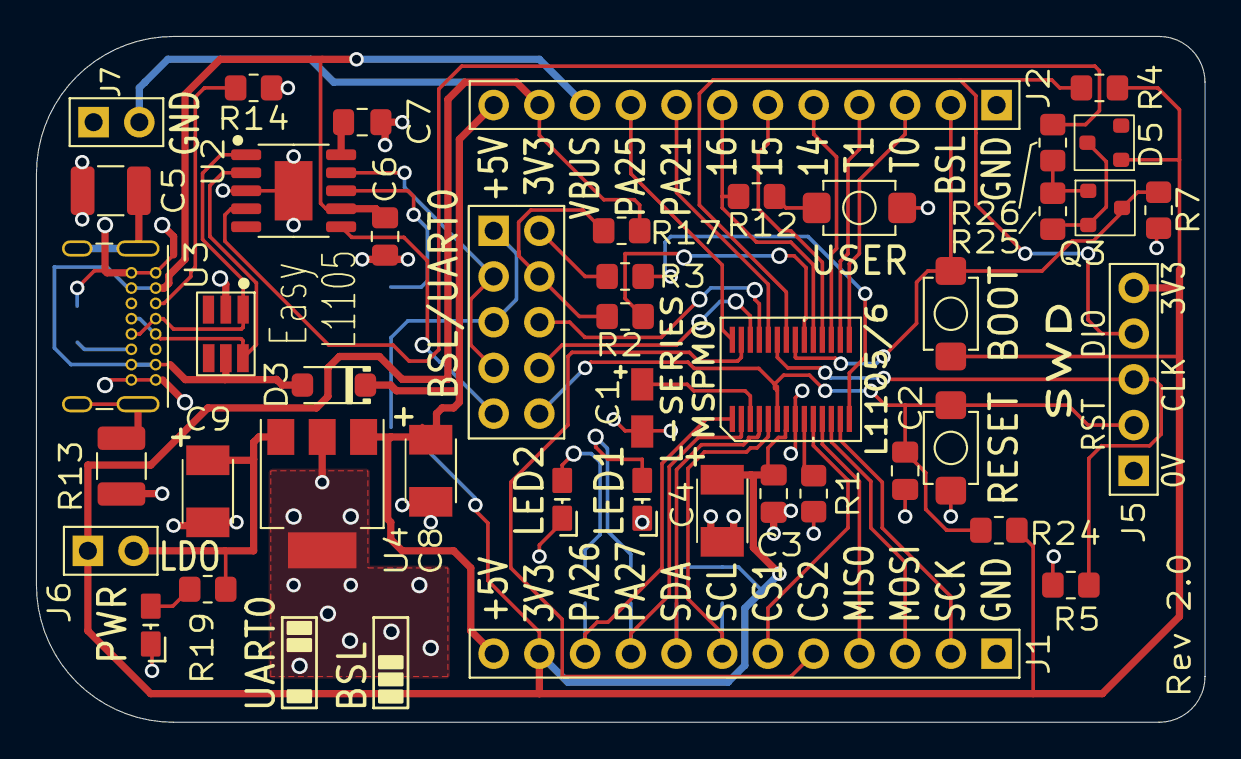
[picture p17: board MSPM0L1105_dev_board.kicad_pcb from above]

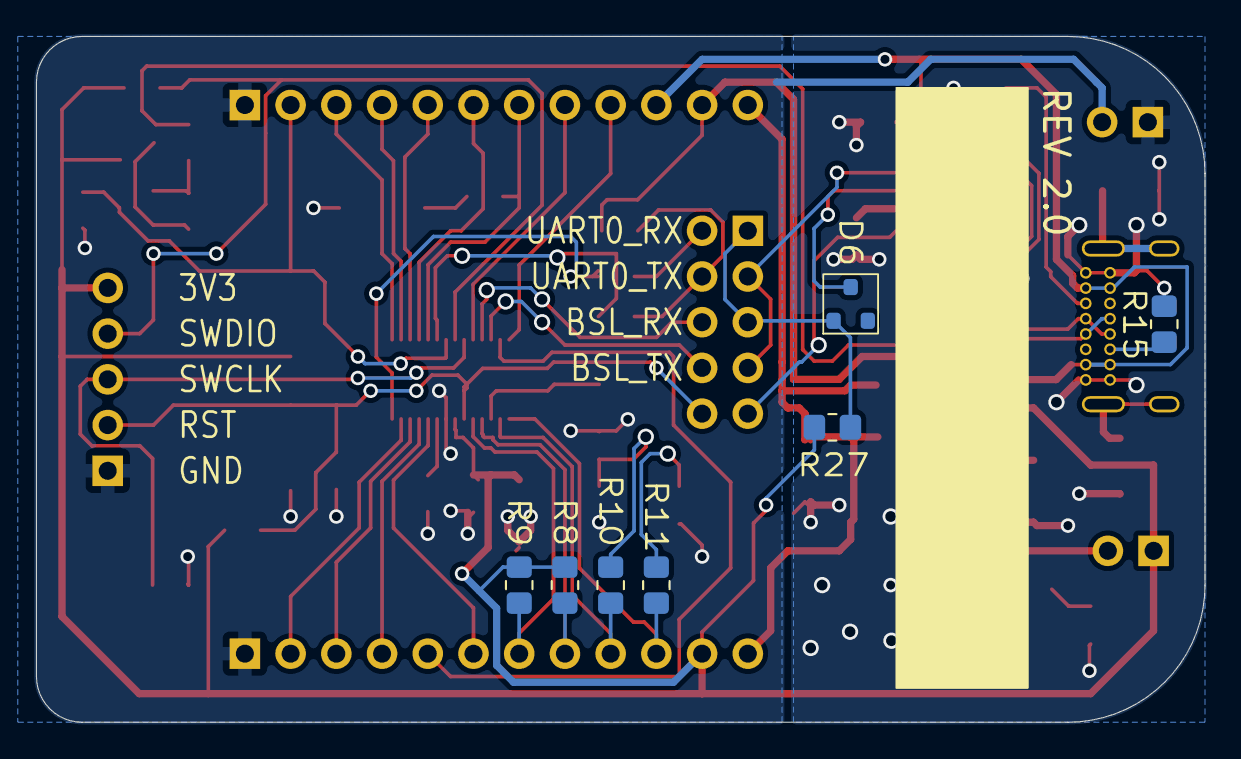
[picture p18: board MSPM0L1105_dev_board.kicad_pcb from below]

Board: 2 copper layers, 64.9 x 38.1 mm, 50 parts (7 on the bottom side), 52 nets.

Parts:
C1: 0.47u; Cap-Tant-T491A
C2: 10n; C_0805_2012Metric_Pad1.18x1.45mm_HandSolder
C3, C6, C7: 100n; C_0805_2012Metric_Pad1.18x1.45mm_HandSolder
C4, C8, C9: 10u; Cap-Tant-CaseB
C5: 10n; C_1210_3225Metric_Pad1.33x2.70mm_HandSolder
D1: GREEN; LED_0603_or_0805
D2: BLUE; LED_0603_or_0805
D3: 1N4001W; D_SOD-123-pins12
D4: RED; LED_0603_or_0805
D5, D6: BAS16; SOT-23-NEW
J1: IO_A; PinHeader_1x12_P2.54mm_Vertical
J2: IO_B; PinHeader_1x12_P2.54mm_Vertical
J3: UART-SELECT; PinHeader_2x5
J4: USB_C_Receptacle_USB4085; USB_C_Receptacle_GCT_USB4085_improved
J5: SWD; PinHeader_1x05_P2.54mm_Vertical
J6: LDO_JUMPER; PinHeader_1x02_P2.54mm_Vertical
J7: GND_JUMPER; PinHeader_1x02_P2.54mm_Vertical
Q3: BC857; SOT-23-NEW
R1: 100k 0.1%; R_0805_2012Metric_Pad1.20x1.40mm_HandSolder
R2, R3, R12: 100R; R_0805_2012Metric_Pad1.20x1.40mm_HandSolder
R4, R5, R7, R17: 100k; R_0805_2012Metric_Pad1.20x1.40mm_HandSolder
R8, R9, R25, R26, R27: 10k; R_0805_2012Metric_Pad1.20x1.40mm_HandSolder
R10: 220R; R_0805_2012Metric_Pad1.20x1.40mm_HandSolder
R11: 820R; R_0805_2012Metric_Pad1.20x1.40mm_HandSolder
R13: 1M; R_1210_3225Metric_Pad1.30x2.65mm_HandSolder
R14, R15: 5.1k; R_0805_2012Metric_Pad1.20x1.40mm_HandSolder
R19: 1k; R_0805_2012Metric_Pad1.20x1.40mm_HandSolder
R24: 47k; R_0805_2012Metric_Pad1.20x1.40mm_HandSolder
SW1: RESET; Tact-SW-4x3mm-body
SW2: BSL_BOOT; Tact-SW-4x3mm-body
SW3: USER_PA16; Tact-SW-4x3mm-body
U1: MSPM0L1105TDGS28R; VSSOP28-DGS-TI
U2: CH340K; SSOP-10-1EP_CH340K
U3: SRV05-4; SOT23-6
U4: MIC5209-3.3YS; SOT-223

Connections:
0V: C1.2, C2.2, C3.2, C4.2, D1.1 (K), D2.1 (K), J1.1, J2.1, J5.1, J7.2, R1.2, R5.2, R7.2, SW1.1, SW3.1, U1.8 (VSS)
+3.3V: C3.1, C4.1, D5.1 (A), J1.11, J2.11, J5.5, J6.1, R4.2, R8.1, R9.1, R17.1, R24.1, R27.1, SW2.2, U1.7 (VDD)
+5V: C8.1, D3.1 (K), J1.12, J2.12, U4.1 (IN)
/*DTR: R26.1, U2.4 (~DTR)
/*RST: C2.1, J3.10, J5.2, R24.2, SW1.2, U1.6 (*RST)
/BSL_INVOKE: J2.2, Q3.3 (C), R7.1, SW2.1, U1.21 (BSL_INVOKE/PA18)
/BSL_RX: J3.6, U1.25 (BSL_RX/PA22/A4)
/BSL_TX: J3.8, U1.26 (BSL_TX/VREF+/PA23)
/CS1: J1.6, U1.10 (CS1/PA3)
/CS2: J1.5, U1.27 (CS2/PA24/A3)
/MISO: J1.4, U1.11 (MISO/PA4)
/MOSI: J1.3, U1.12 (MOSI/PA5)
/PA9: R3.2, U1.14 (RXD/PA9)
/PA14: J2.5, U1.17 (PA14)
/PA15: J2.6, U1.18 (PA15/A9)
/PA16: J2.7, R12.2, U1.19 (PA16/A8)
/PA21: J2.8, U1.24 (VREF-/PA21/A5)
/PA25: J2.9, U1.28 (PA25/A2)
/PA26: J1.10, R11.1, U1.1 (PA26/A1)
/PA27: J1.9, R10.1, U1.2 (PA27/A0)
/RXD: D6.3 (K), U2.8 (TXD)
/SCK: J1.2, U1.13 (SCK/PA6)
/SCL: J1.7, R9.2, U1.5 (SCL/PA1)
/SDA: J1.8, R8.2, U1.4 (SDA/PA0)
/SWCLK: J5.3, R5.1, U1.23 (SWCLK/PA20/A6)
/SWDIO: J5.4, R4.1, U1.22 (SWDIO/PA19)
/TIMG4_C0: J2.3, U1.15 (TIMG4_C0/PA10)
/TIMG4_C1: J2.4, U1.16 (TIMG4_C1/PA11)
/TXD: J3.3, J3.7, U2.9 (RXD)
/UART0_RXD: J3.2, R3.1
/UART0_TXD: J3.4, R2.1, R17.2
Earth: C5.2, C6.1, C7.2, C8.2, C9.2, D4.1 (K), J4.A1 (GND), J4.A12 (GND), J4.B1 (GND), J4.B12 (GND), J7.1, R13.2, R14.2, R15.2, U2.3 (GND), U2.11 (GND), U3.2 (VN), U4.2 (GND)
unnamed: C5.1, J4.S1 (SHIELD)
unnamed: D1.2 (A), R10.2
unnamed: D2.2 (A), R11.2
unnamed: D4.2 (A), R19.2
unnamed: D5.3 (K), Q3.2 (E), R25.1
unnamed: D6.1 (A), J3.1, J3.5, R27.2
unnamed: J3.9, U2.6 (~RTS)
unnamed: J4.A5 (CC1), R14.1
unnamed: J4.B5 (CC2), R15.1
unnamed: J4.S2 (SHIELD), R13.1
unnamed: C9.1, J6.2, R19.1, U4.3 (OUT)
unnamed: Q3.1 (B), R25.2, R26.2
unnamed: R12.1, SW3.2
unnamed: R1.1, U1.9 (ROSC/PA2)
unnamed: R2.2, U1.20 (TXD/PA17)
unnamed: C1.1, U1.3 (VCORE)
unnamed: J4.A6 (D+), J4.B6 (D+), U2.1 (D+), U3.1 (IO1)
unnamed: J4.A7 (D-), J4.B7 (D-), U2.2 (D-), U3.6 (IO4)
unnamed: C7.1, U2.10 (V3)
VBUS: C6.2, D3.2 (A), J2.10, J4.A4 (VBUS), J4.A9 (VBUS), J4.B4 (VBUS), J4.B9 (VBUS), U2.7 (VCC), U3.5 (VP)

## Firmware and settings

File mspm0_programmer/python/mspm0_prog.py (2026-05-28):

# MSPM0 BSL Programmer
# rev 1 - shabaz - August 2025
# This program can be used to program MSPM0L110x devices via USB Serial Bootloader (BSL).
# Requires:
# pySerial:  pip install pyserial
# Usage:
# python ./mspm0_prog.py [--port COMx] [--auto] firmware.hex
# python ./mspm0_prog.py --port none --saveflashfile firmware.hex
# python ./mspm0_prog.py [--port COMx] [--auto] firmware.flash  (todo - not currently implemented!)
# python ./mspm0_prog.py [--port COMx] sim
# By specifying firmware.hex, the code will convert to a binary flash file, and then program it
# By specifying firmware.flash, the code will program the flash file directly
# By specifying sim, the code will simulate the MSPM0 BSL and respond to commands
# the --auto option will not prompt the user, and will automatically try to boot/reset the device
# the --saveflashfile option will save the interim flash file with a .flash suffix

import argparse
import serial
import binascii
import time

port = 'COM6'  # Adjust this to your serial port
baudrate = 9600  # Standard baudrate for MSPM0 BSL
ser = None  # Serial port object, initialized later

# bytearray to hold the entire data packet to send over serial port.
# format will be:
# byte 1: Header
# byte 2, 3: Length (2 bytes)
# byte 4: Command
# byte 5..n: Optional Data
# last 4 bytes: CRC32-ISO3309 polynomial bit reversed, inital seed 0xFFFFFFFF
data_packet = bytearray()
# bytearray to hold entire flash data that was sent; 
# this is used for a checksum for standalone verification
data_for_verification_calc = bytearray()

# data pulled from .hex file, for building an 'interim' file that is easier to use
addr_len_list= []  # List of tuples (address, length) for each address range
data_list = []  # List of bytearrays to hold the data for each address range
interim_file_data = bytearray()  # This will hold the interim file data

# serial port capabilities; set to False if you don't want to use RTS/DTR
rts_capability = True
dtr_capability = True

# calc_crc - calculates CRC32 bytes for the entire given payload.
# example: to calculate CRC for data_packet[3:] (after header and 2-byte length):
# calc_crc(data_packet[3:])
# Note: when simulating the microcontroller end, ensure 4 bytes are skipped, since here is a 0x00 prepended.
def calc_crc(payload):
    """Calculate CRC32 (IEEE/ISO, reflected), covering bytes after header+length, and append LE."""
    crc = (binascii.crc32(payload, 0) ^ 0xFFFFFFFF) & 0xFFFFFFFF
    return crc.to_bytes(4, 'little')

# Build packet with the given header, command and optional data
# Example: Header = 0x80, Command = 0x12, Data = [], CRC32=4 bytes
# Result will be [0x80, 0x01, 0x00, 0x12, 0x3a, 0x61, 0x44, 0xde]
def build_packet(header, command, data):
    """Create a data packet with the given header, command and optional data and CRC32."""
    global data_packet
    length = len(data) + 1  # +1 for the command byte
    data_packet.clear()  # Clear previous data packet
    data_packet.append(header)
    data_packet.extend(length.to_bytes(2, 'little'))  # Length is 2 bytes
    data_packet.append(command)
    data_packet.extend(data)  # Append optional data
    data_packet.extend(calc_crc(data_packet[3:]))  # Calculate and append CRC
    # print(f"Data packet built: {data_packet.hex()}")

def sanity_check():
    # data is a bytearray of 32 0xff bytes
    data = bytearray([0xff] * 32)
    build_packet(0x80, 0x21, data)
    expected = bytearray([0x80, 0x21, 0x00, 0x21]) + data + bytearray([0x02, 0xaa, 0xf0, 0x3d])
    if data_packet != expected:
        print(f"***** ERROR - Sanity check failed: {data_packet.hex()} != {expected.hex()}")
        exit(1)
    else:
        print("Sanity check passed.")

def print_banner():
    print("\n\n\n\n\n\n");
    print("                      _     __ __  ___  _____ ");
    print("                     | |   /_ /_ |/ _ \| ____|");
    print("  ___  __ _ ___ _   _| |    | || | | | | |__  ");
    print(" / _ \/ _` / __| | | | |    | || | | | |___ \ ");
    print("|  __/ (_| \__ \ |_| | |____| || | |_| |___) |");
    print(" \___|\__,_|___/\__, |______|_||_|\___/|____/ ");
    print("                 __/ |                        ");
    print("                |___/                         ");
    print("MSPM0 BSL Programmer - rev 1 - shabaz - August 2025")
    print(" ");


def hexparse(hex_file):
    """Read an Intel HEX file to memory and parse it into address and data lists."""
    global addr_len_list
    global data_list

    addr_len_list = []
    data_list = []

    cur_data_bytes = bytearray()
    max_data_len = 1024
    tot_data_len = 0
    upper_addr_word = 0x0000

    current_range_start = None  # track the start address for the current contiguous range

    def flush_current():
        """Flush cur_data_bytes into data_list/addr_len_list using 1024-byte chunks + final partial."""
        nonlocal cur_data_bytes, current_range_start, tot_data_len
        if current_range_start is None or len(cur_data_bytes) == 0:
            return
        start = current_range_start
        buf = cur_data_bytes
        # full 1024-byte chunks
        while len(buf) >= max_data_len:
            data_list.append(bytearray(buf[:max_data_len]))
            addr_len_list.append((start, max_data_len))
            tot_data_len += max_data_len
            buf = buf[max_data_len:]
            start += max_data_len
        # final partial (if any)
        if len(buf) > 0:
            data_list.append(bytearray(buf))
            addr_len_list.append((start, len(buf)))
            tot_data_len += len(buf)
        # reset
        cur_data_bytes = bytearray()
        current_range_start = None

    with open(hex_file, 'r') as f:
        for line_num, line in enumerate(f, start=1):
            line = line.strip()
            if not line or not line.startswith(':'):
                print(f"line # {line_num}: Skipping content: '{line}'")
                continue
            print(f"processing line {line_num}: {line}")
            try:
                byte_count  = int(line[1:3], 16)
                addr16      = int(line[3:7], 16)
                record_type = int(line[7:9], 16)
                data        = bytes.fromhex(line[9:9 + 2*byte_count])
            except ValueError as e:
                print(f"Error parsing line '{line}': {e}")
                continue  # keep going
            if record_type == 4:
                # Extended Linear Address
                upper_addr_word = int.from_bytes(data, 'big') << 16
            elif record_type == 0:
                # Data record
                addr32 = (upper_addr_word | addr16) & 0xFFFFFFFF
                # Start new range or check contiguity
                if current_range_start is None:
                    current_range_start = addr32
                elif addr32 != (current_range_start + len(cur_data_bytes)):
                    # non-contiguous -> flush current range first
                    flush_current()
                    current_range_start = addr32
                # append incoming bytes
                cur_data_bytes.extend(data)
                # Split out any full 1024-byte chunks immediately
                while len(cur_data_bytes) >= max_data_len:
                    data_list.append(bytearray(cur_data_bytes[:max_data_len]))
                    addr_len_list.append((current_range_start, max_data_len))
                    tot_data_len += max_data_len
                    cur_data_bytes = cur_data_bytes[max_data_len:]
                    current_range_start += max_data_len
            elif record_type == 1:
                print(f"End of file record (0x01) on line {line_num}, finished reading .hex file")
                break
            else:
                # other record types
                continue
    # Final flush
    flush_current()

    # Sanity checks
    print(f"Sanity checking the .hex content...")
    if len(addr_len_list) != len(data_list):
        print(f"**** ERROR: Length of addr_len_list ({len(addr_len_list)}) does not match length of data_list ({len(data_list)}), aborting! ****")
        return False

    for addr, length in addr_len_list:
        if length == 0:
            print(f"**** ERROR: Address {addr:#010x} has length 0, aborting! ****")
            return False
        if addr % 8 != 0:
            print(f"**** ERROR: Address {addr:#010x} is not 8-byte aligned, aborting! ****")
            return False

    # pad to 8B if needed
    for i, (addr, length) in enumerate(addr_len_list):
        if length % 8 != 0:
            padding_length = 8 - (length % 8)
            addr_pad_start = addr + length
            addr_pad_stop  = addr_pad_start + padding_length - 1
            print(f"Data length for Entry {i} is not divisible by 8, padding..")
            print(f"Padding Entry {i} with {padding_length} x '0xff' byte(s) at {addr_pad_start:#010x}-{addr_pad_stop:#010x}")
            data_list[i] += bytearray([0xff] * padding_length)
            addr_len_list[i] = (addr, length + padding_length)

    for i, (addr, length) in enumerate(addr_len_list):
        print(f"  Addr/Len Entry {i}: Address: {addr:#010x}, Length: {length} bytes")
    for i, data in enumerate(data_list):
        print(f"  Data Entry {i}: Length: {len(data)} bytes, Content: {data.hex()}")


def build_interim_array():
    """Build an interim file array from the address and data lists that came from the parsed hex file."""
    global interim_file_data
    interim_file_data.clear()  # Clear previous data
    # interim array format:
    # 256 bytes: set to 0x00 for now
    # 4 bytes: 'ADDR' (ASCII)
    # 2 bytes: number of addr_len entries (little-endian)
    # addr_len section: 6 bytes per entry, 4 bytes address, 2 bytes length (little-endian)
    # 4 bytes: 'DATA' (ASCII)
    # 2 bytes: length of first data entry in bytes (little-endian)
    # n bytes: data for the first address range
    # 2 bytes: length of second data entry in bytes (little-endian)
    # n bytes: data for the second address range
    # ... and so on for all address ranges

    interim_file_data.extend(bytearray(256))  # Fill the first 256 bytes with 0x00
    interim_file_data.extend(b'ADDR')  # Append 'ADDR' ASCII
    interim_file_data.extend(len(addr_len_list).to_bytes(2, 'little'))  # Number of addr_len entries in little-endian format
    # Append the addr_len_list entries
    for addr, length in addr_len_list:
        interim_file_data.extend(addr.to_bytes(4, 'little'))
        interim_file_data.extend(length.to_bytes(2, 'little'))
    interim_file_data.extend(b'DATA')  # Append 'DATA' ASCII
    # Append the data entries
    for i, data in enumerate(data_list):
        interim_file_data.extend(len(data).to_bytes(2, 'little'))  # Length of data entry in bytes
        interim_file_data.extend(data)  # Append the data bytes
    # Print the interim file data for debugging
    # print in format: idx : data (hex) : data (ascii) 16 bytes per line
    print("Interim file data:")
    for i in range(0, len(interim_file_data), 16):
        line = interim_file_data[i:i+16]
        hex_data = ' '.join(f'{b:02x}' for b in line)
        ascii_data = ''.join(chr(b) if 32 <= b < 127 else '.' for b in line)
        print(f"{i:04x} : {hex_data:<48} : {ascii_data}")
    return True
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

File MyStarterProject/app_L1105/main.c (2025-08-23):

/***********************************************
 * main.c
 * rev 1 - shabaz - August 2025
 * TI DriverLib documentation:
 * https://software-dl.ti.com/msp430/esd/MSPM0-SDK/latest/docs/english/driverlib/mspm0l11xx_l13xx_api_guide/html/index.html
 ***********************************************/

#include <stdint.h>
#include "ti_msp_dl_config.h"

// output pins
#define GREEN_LED 27
#define BLUE_LED 26
#define BIT(n) (1U << (n))

// sets a GPIO pin as output. Use pin_num from 0 to 27, for PA0-PA27
void set_output(uint32_t pin_num) {
    DL_GPIO_initDigitalOutput(pin_num);
    DL_GPIO_clearPins(GPIOA, BIT(pin_num));
    DL_GPIO_enableOutput(GPIOA, BIT(pin_num));
}

// delay function, chews up CPU time
void delay_ms(uint32_t ms)
{
    for (uint32_t j = 0; j < ms; j++) {
        // might need the value adjusting
        for (volatile uint32_t i = 0; i < 2000; i++) {
            __asm volatile ("nop");
        }
    }
}

/********************************
 * main function
 ********************************/
int main(void)
{
    // power up GPIO feature
    DL_GPIO_reset(GPIOA);
    DL_GPIO_enablePower(GPIOA);
    delay_cycles(16);
    
    // set LED pins as outputs
    set_output(GREEN_LED);
    set_output(BLUE_LED);
    
    // forever loop
    while (1) {
        DL_GPIO_writePins(GPIOA, BIT(GREEN_LED));
        DL_GPIO_clearPins(GPIOA, BIT(BLUE_LED));
        delay_ms(200);
        DL_GPIO_writePins(GPIOA, BIT(BLUE_LED));
        DL_GPIO_clearPins(GPIOA, BIT(GREEN_LED));
        delay_ms(200);
    }
    
    return(0); // warning on this line is OK
}

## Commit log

2025-08-22 Document known bug and fix for easyL1105 boards
    Added note about known bug and fix for easyL1105 boards.
2025-08-23 Add circuit diagrams section to README
    Added circuit diagrams for easyL1105 and miniL1105 boards.
2025-09-06 Add parts list for easyL1105 board
    Added a detailed parts list for the easyL1105 board, including component references, quantities, values, and descriptions.
2025-09-27 Flash erase command corrected to use end address, not length
    [mspm0_prog.py]
2026-05-26 Rev 2.0
    [MSPM0L1105_dev_board.kicad_pcb, MSPM0L1105_dev_board.kicad_sch]
2026-05-26 Make schematic images clickable in main README
    Agent-Logs-Url: https://github.com/shabaz123/easyL1105/sessions/3d091ee9-08be-49fd-95bf-b4872f04906b
2026-05-26 Fix image links in README for circuit diagrams
    Updated the README to use proper HTML anchor tags for circuit diagram images.
